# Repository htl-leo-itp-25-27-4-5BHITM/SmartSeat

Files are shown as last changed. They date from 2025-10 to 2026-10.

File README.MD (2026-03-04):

# SmartSeat

**Projektteam:**  
Daniel Riemer, Joschua Auer, Nino Tesar, Stefan Meinhart  
**Klasse:** 4BHITM – Schuljahr 2025/26  

---

## Projektübersicht

###
***TechStack***

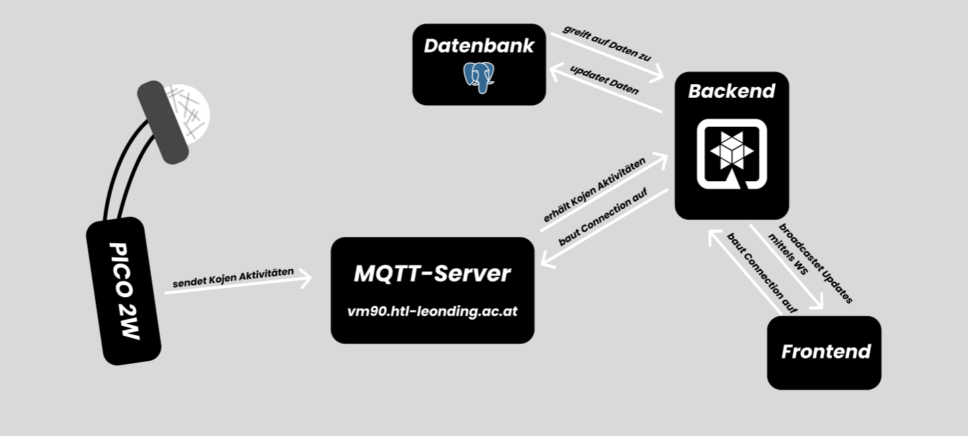
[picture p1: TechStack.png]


### Projektbezeichnung
**SmartSeat**

### Projektauftraggeber
- Dietmar Steiner  
- Christian Aberger  
- Dejan Sivak  

---

## Projekthintergrund und Motivation

Lernkojen sind fast durchgehend belegt, jedoch ist für Schüler auf den ersten Blick nicht ersichtlich, welche Koje aktuell frei ist.  
Die Suche nach einem freien Platz kann bis zu 10 Minuten dauern – Zeit, die verloren geht, da man bald wieder in den Unterricht zurückkehrt.

Auch für Lehrkräfte entstehen Probleme:
- Kommunikation mit Schülern ist oft umständlich.  
- Informationen oder organisatorische Hinweise müssen mehrfach einzeln übermittelt werden.  
- Das führt zu Unübersichtlichkeit, Missverständnissen und Frustration.

Das Projekt kann künftig auch für andere Orte wie Kindergärten, Kantinen oder allgemeine Platzverwaltungssysteme eingesetzt werden.

---

## Projektziele und Meilensteine

### 4. Klasse – 1. Semester
1. Web-App-Layout in Figma erstellt  
2. Grundstruktur der Web-App  
3. REST API aufgesetzt  
4. Datenbank aufgesetzt  
5. Raspberry-Pi-Kommunikation aufgebaut  

### 4. Klasse – 2. Semester
1. Karte in die App eingebunden  
2. App-Layout verfeinert  
3. Login implementiert  
4. Lehrerverwaltung eingebunden  

---

## Zielgruppe

- Schülerinnen und Schüler  
- Lehrkräfte  

---

## Technologie-Stack

### Software
- Backend: Quarkus  
- Datenbank: H2  
- Frontend: HTML, CSS, JavaScript (optional: Angular oder Vue)  
- Containerisierung: Docker  
- Microcontroller: MicroPython / C  

### Hardware
- Raspberry Pi Pico 2WH  
- Physischer Knopf  
- Ultraschallsensoren  

---

## SWOT-Analyse

| Kategorie | Punkte |
|---|---|
| **Strengths** | Gute Kenntnisse in SQL, HTML, CSS und JS |
| **Weaknesses** | Angular wird erst später gelernt; Quarkus ist noch neu; Datenübertragung zwischen Raspberry Pi, Quarkus und Datenbank kann komplex sein |
| **Opportunities** | Erweiterbar für viele andere Bereiche (z. B. Kindergärten, Kantinen, Raumbelegung) |
| **Threats** | Raspberrys könnten durch unsachgemäße Nutzung beschädigt werden |

---

## Sinn, Zweck und USP

### Ziel des Endprodukts
Eine Web-App, über die man sehen kann:
- Welche Lernkojen frei sind  
- Wo sich diese befinden  

In jedem Klassenraum hängt ein QR-Code, der direkt zur Website führt.

### Funktionen
- **Für Schüler:**  
  Nach dem Scannen sehen sie sofort freie Lernkojen.  
- **Für Lehrkräfte:**  
  Sie sehen, wo Schüler sitzen, und können Nachrichten an einzelne Kojen oder an die ganze Klasse senden.

### USP (Unique Selling Proposition)
Unsere Web-App macht freie Lernkojen auf einen Blick sichtbar, ermöglicht Schülern eine schnelle Kojensuche per QR-Code und bietet Lehrkräften gleichzeitig einen Überblick sowie eine direkte Kommunikationsmöglichkeit mit einzelnen Kojen oder der gesamten Klasse.

---

## Projektorganisation

| Name | Verantwortungsbereich |
|---|---|
| Nino Tesar | Backend |
| Daniel Riemer | Hauptsächlich Frontend |
| Joschua Auer | Hauptsächlich Frontend |
| Stefan Meinhart | Hardware |

---

© 2025 – SmartSeat Projektteam, 4BHITM

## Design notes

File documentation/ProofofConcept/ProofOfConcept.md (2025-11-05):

# Sensorbasierte Platzbelegung

---

## 1. Raspberry Pi Pico 2 WH

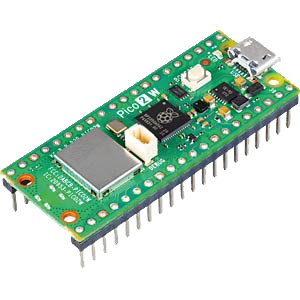
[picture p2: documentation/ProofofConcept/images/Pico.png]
Platzhalter für Raspberry Pi Pico Bild


[Produktlink bei Reichelt](https://www.reichelt.at/at/de/shop/produkt/raspberry_pi_pico_2_wh_rp235x_cortex-m33_wifi_microusb-398576)  
**Preis:** 9 €

### Beschreibung
Der **Raspberry Pi Pico 2 WH** wertet **Sensoren, Knöpfe und NFC-Daten** aus und sendet diese an das **Backend**.

---

### Vorteile
- Flexible **Sensor-Kombinationen** (Ultraschall, Knopf, Bewegung, NFC)  
- Viele **Hardware-Erweiterungen** verfügbar  
- Ideal für **schnelle Prototypen**  
- **Eigene Datenübertragung**, keine Fremd-APIs nötig  
- **Gut dokumentiert** & viele **Tutorials** verfügbar  

---

### Nachteile
- **Preis** summiert sich bei vielen Einheiten  
- **Zusammenbau** erforderlich → zusätzliche Kosten  
- **Programmierung** des Microcontrollers notwendig  

---

### Sensoren (Beispiele)

#### 🔸 Bewegungssensor (PIR HC-SR501)
- [Reichelt-Link](https://www.reichelt.at/at/de/shop/produkt/raspberry_pi_-_infrarot_bewegungsmelder_pir_hc-sr501-224216)  
- Reichweite: **3 m**  
- Preis: **2,30 €**

#### 🔸 Ultraschallsensor (HC-SR04)
- [Reichelt-Link](https://www.reichelt.at/at/de/shop/produkt/entwicklerboards_-_ultraschall_abstandssensor_hc-sr04-161487)  
- Messbereich: **3–400 cm**  
- Preis: **3,83 €**

#### 🔸 NFC-Modul (MFRC-522)
- [Reichelt-Link](https://www.reichelt.at/at/de/shop/produkt/entwicklerboards_-_rfid-modul_nxp_mfrc-522-192147)  
- Preis: **7 €**

#### 🔸 IR-Lichtschranken (2 × pro Koje)
- **Empfänger:** [IR-Empfänger](https://www.reichelt.at/at/de/shop/produkt/arduino_-_ir-empaenger-282519) → **1,56 €**  
- **Sender:** [IR-Sender](https://www.reichelt.at/at/de/shop/produkt/arduino_-_ir-sendermodul-282523) → **1,61 €**
> Solange die Lichtschranke unterbrochen ist, wird die Koje als **besetzt** markiert.

#### 🔸 Kabel
- Länge: **50cm * 20**
- Preis: **7,16€**

---

## 2. Tuya-Bewegungsmelder

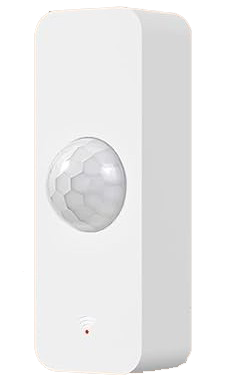
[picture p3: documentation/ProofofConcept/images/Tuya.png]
Platzhalter für Tuya-Bewegungsmelder Bild


[Amazon-Link](https://www.amazon.de/WiFi-Bewegungssensor-Bewegungsmelder-Heimsicherheit-Fernüberwachungs/dp/B0CLY2H1H6/)  
**Preis:** ca. **50 € (4 Stück)**  

---

### Zugriffsmöglichkeiten

#### 🔸 Lokale WLAN-Steuerung
- Schnellere Reaktion als Cloud-Steuerung  
- Notwendige Daten:  
  - **Device ID**, **Local Key**, **IP-Adresse**, **DP-Codes**  
- Tools: **tinytuya (Python)** kann Geräte im LAN scannen  
- Bewegungen → DP-Code (z. B. `101`) = `true/false`

#### 🔸 Cloud-Steuerung
- Über **Tuya IoT Console** ([iot.tuya.com](https://iot.tuya.com))  
- Geräteverknüpfung per **QR-Code**  
- Zugriff auf **Device ID**, **Local Key**, **DP-Codes**  
- Integration in eigene Software möglich
- **KO Kriterien:**
  - 1 Monat Free Trial
  - Standard Version: 300€ pro Monat  

---

### Integration mit Quarkus REST API
- Statusabfrage über **Listener (Push)** oder **Polling**  
- **Port:** 6668  
- **Verschlüsselung:** AES-128-ECB  

---

### Technische Daten

| Merkmal | Wert |
|---|---|
| Typ | Drahtloser Bewegungsmelder |
| Reichweite | 6 m |
| Stromversorgung | Batterie |
| Anzahl / Preis | 4 Stk. ≈ 50 € |
| Technologie | Infrarot, WiFi |
| Laufzeit | Bis zu 6 Monate |
| Stromverbrauch | Niedrig |

---

## 3. Ultraschallsensoren (Alternative Lösung)

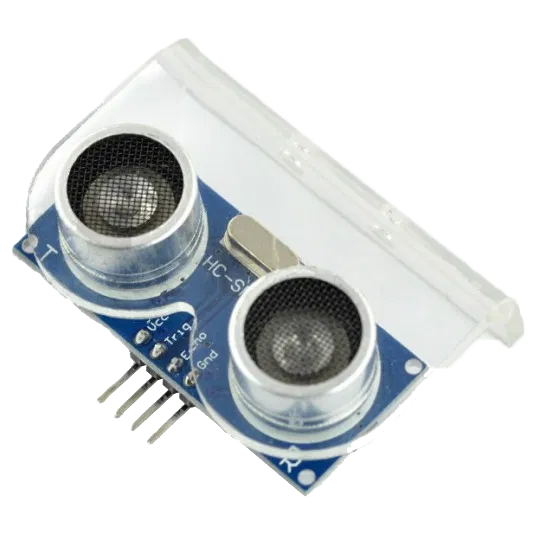
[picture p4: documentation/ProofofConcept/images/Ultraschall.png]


[Botland-Link](https://botland.de/ultraschall-abstandssensoren/5686-ultraschall-abstandssensor-hc-sr04-2-200cm-montagehalterung-5904422308452.html)  
**Preis:** 3 € pro Stück → mind. 2 Sensoren nötig  

---

### Vorteile
- Sehr **günstig**  
- **Einfache Verwendung**  
- Bereits **bekannte Technologie**

### Nachteile
- **Fehlauslösung** möglich (Objekt im Weg)  
- **Unzuverlässig** bei bestimmten Materialien oder Winkeln  
- **Weitere Hardwarekomponenten** nötig  

---

## 4. NFC-Reader (für Platzbelegung)

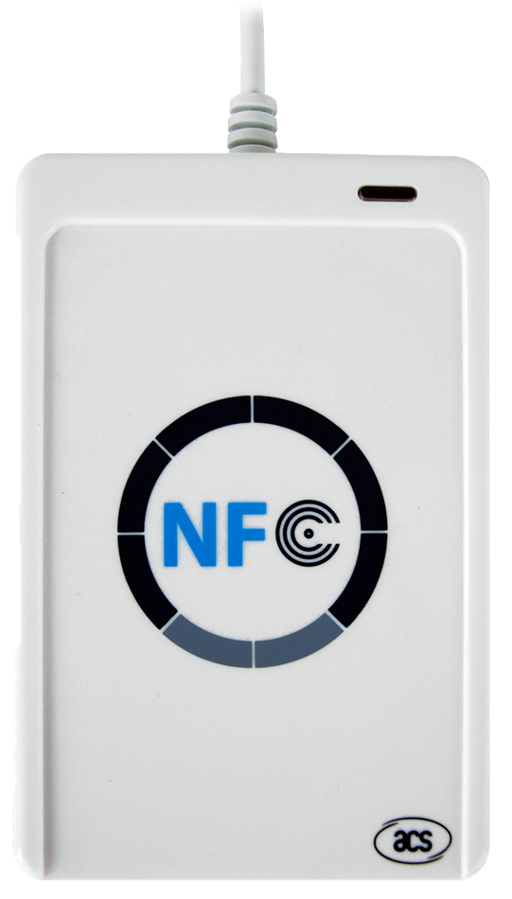
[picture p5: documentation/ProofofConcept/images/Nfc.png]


### Funktionsprinzip
Beim Platznehmen hält der Schüler sein **Smartphone oder Karte** an den **NFC-Reader**.  
→ Die Koje wird in der Datenbank als **„besetzt“** markiert.  
Beim Verlassen wiederholt er den Vorgang → **„frei“**.

---

### Vorteile
- Sehr **praktisch** – Handy ist immer dabei  
- **Schnelle Anmeldung**

### Nachteile
- **Nicht jedes Handy** unterstützt NFC-HCE  
- **Apple-Geräte** nur eingeschränkt kompatibel  
- **Nur Teil der Nutzer** kann das Feature verwenden  
- Benötigt speziellen **NFC-Reader mit HCE-Unterstützung**

---

## Zusammenfassung (Vergleich)

| Komponente | Preis | Vorteile | Nachteile |
|---|---|---|---|
| **Raspberry Pi Pico 2 WH** | 9 € | Erweiterbar, dokumentiert | Aufbau & Programmierung nötig |
| **Tuya-Bewegungsmelder** | 50 € (4 Stk.) | WLAN & Cloud ready | Teilweise Cloud-abhängig |
| **Ultraschallsensoren** | 3 €/Stk. | Günstig & einfach | Fehleranfällig |
| **NFC-Reader (ESP32 + NFC)** | 55 € | Handy-Integration | Nicht alle Geräte kompatibel |

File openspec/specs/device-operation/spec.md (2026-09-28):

# Device Operation Specification

## Purpose

Defines how the supported Raspberry Pi Pico 2 W motion-sensor unit starts, observes a seat, publishes data, reconnects, and exposes diagnostics.

## Requirements

### Requirement: Supported baseline device
The baseline occupancy device SHALL be a Raspberry Pi Pico 2 W connected to one motion sensor whose signal output is wired to GPIO 18, with appropriate power and ground connections.

#### Scenario: Correctly wired startup
- **WHEN** the device receives stable USB power and the sensor is wired to the documented pins
- **THEN** the firmware initializes the GPIO input without requiring an interactive start command

### Requirement: Network startup
The device SHALL use externally supplied Wi-Fi and MQTT configuration, connect to the configured network, and establish an MQTT session before publishing observations.

#### Scenario: Network available
- **WHEN** configured Wi-Fi and MQTT services are reachable
- **THEN** the device connects and becomes ready to publish observations

#### Scenario: Network unavailable at boot
- **WHEN** Wi-Fi or MQTT is unavailable during startup
- **THEN** the device reports the failure through diagnostics and continues bounded reconnection attempts without crashing

### Requirement: Seat-specific observation publication
Each device SHALL be configured with one seat identifier and SHALL publish observations using the sensor-ingestion contract when motion state changes.

#### Scenario: Motion begins
- **WHEN** the motion sensor changes from no motion to motion detected
- **THEN** the device publishes the configured seat identifier with `status=false`

#### Scenario: Motion ends
- **WHEN** the motion sensor changes from motion detected to no motion
- **THEN** the device publishes the configured seat identifier with `status=true`

### Requirement: Continued occupancy refresh
While motion remains detected, the device SHALL publish observations often enough to prevent a genuinely occupied seat from expiring solely because no edge transition occurred.

#### Scenario: Continuous motion state
- **WHEN** a seat remains occupied longer than the configured inactivity duration
- **THEN** periodic valid observations refresh the backend last-observed time without creating another interval

### Requirement: Connection recovery
The device SHALL recover from temporary Wi-Fi or MQTT loss and resume publication without requiring a power cycle under normal recoverable conditions.

#### Scenario: MQTT connection drops
- **WHEN** an established MQTT connection is lost
- **THEN** the device retries with bounded backoff and publishes the current observation after reconnecting

### Requirement: Local diagnostics
The device SHALL make startup, connection, publication, and unrecoverable error status observable through its serial diagnostic output without printing reusable secrets.

#### Scenario: Inspect serial output
- **WHEN** an operator connects a serial monitor to the device
- **THEN** the output identifies operational state and failures without revealing Wi-Fi or MQTT passwords

### Requirement: Prototype alternatives remain excluded
NFC, Tuya, ultrasonic, button, and infrared-barrier devices SHALL NOT be required for baseline operation unless adopted by a later approved specification change.

#### Scenario: Baseline acceptance test
- **WHEN** SmartSeat is tested against this baseline
- **THEN** the test does not require any excluded proof-of-concept sensor technology

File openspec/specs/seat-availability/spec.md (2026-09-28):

# Seat Availability Specification

## Purpose

Defines how people discover current learning-seat availability without authentication and how the view remains accurate as occupancy changes.

## Requirements

### Requirement: Public availability access
The system SHALL allow a user to view seat availability without signing in.

#### Scenario: Open availability view
- **WHEN** a user opens the SmartSeat public entry point
- **THEN** the system displays the current seat-availability view without requesting credentials

#### Scenario: Administrative functions remain separate
- **WHEN** an unauthenticated user uses the public availability view
- **THEN** the system does not expose controls that modify seats, configuration, accounts, or history

### Requirement: Seat availability presentation
The system SHALL present each configured seat with its stable identifier, display name, floor, wing, and canonical state of `FREE`, `OCCUPIED`, or `UNKNOWN`.

#### Scenario: Display free and occupied seats
- **WHEN** the current catalog contains seats in free and occupied states
- **THEN** the map and list distinguish those states consistently and provide a textual state indicator in addition to color

#### Scenario: Display unknown state
- **WHEN** the system cannot establish a trustworthy current state for a configured seat
- **THEN** the public view identifies the seat as `UNKNOWN` rather than reporting it as free

### Requirement: Location filtering and counts
The system SHALL allow users to filter seats by configured location and SHALL calculate free-seat counts from the same filtered dataset shown to the user.

#### Scenario: Filter by floor
- **WHEN** a user selects a floor
- **THEN** only seats assigned to that floor are shown and the free-seat count reflects those seats

#### Scenario: Location has no seats
- **WHEN** a user selects a known location that has no configured seats
- **THEN** the system shows an empty result and a free-seat count of zero without reporting an error

### Requirement: Live availability updates
The system SHALL deliver a complete current seat snapshot when a realtime connection is established and SHALL publish subsequent state or catalog changes to connected clients.

#### Scenario: Realtime state change
- **WHEN** an occupied seat becomes free or a free seat becomes occupied
- **THEN** connected public views update that seat without requiring a page reload

#### Scenario: Reconnect after interruption
- **WHEN** a client restores a lost realtime connection
- **THEN** the system sends a fresh complete snapshot before applying later incremental changes

### Requirement: Current occupancy duration
The system SHALL show the elapsed duration of the current occupancy interval for an occupied seat and SHALL omit that duration for free or unknown seats.

#### Scenario: Occupied seat duration
- **WHEN** a user inspects a seat with an active occupancy interval
- **THEN** the displayed elapsed duration is derived from the recorded interval start and the current time

#### Scenario: Seat becomes free
- **WHEN** an occupied seat transitions to free
- **THEN** the public view stops displaying an active occupancy duration for that seat

### Requirement: Location-specific QR entry
The system SHALL support QR-code URLs that open the public availability view with a configured location already selected.

#### Scenario: Valid location QR code
- **WHEN** a user follows a QR-code URL for a known location
- **THEN** the public view opens with that location filter applied

#### Scenario: Invalid location QR code
- **WHEN** a QR-code URL references an unknown location
- **THEN** the system shows the unfiltered availability view and explains that the requested location was not found

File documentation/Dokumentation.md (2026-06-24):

# **Smartseat Gebrauchsanweisungs**

## MQTT und der Sensor

Damit wir wissen welche Kojen besetzt sind, verweden wir einen Pico 2W mit einem Bewegungssensor.

### Entwicklung 

Für Entwicklungszwecken kann man die MQTT-Eingaben, durch Programme wie MQTT-Explorer simulieren, dabei verwenden wir den MQTT Server vom Herrn Professor Stützt.

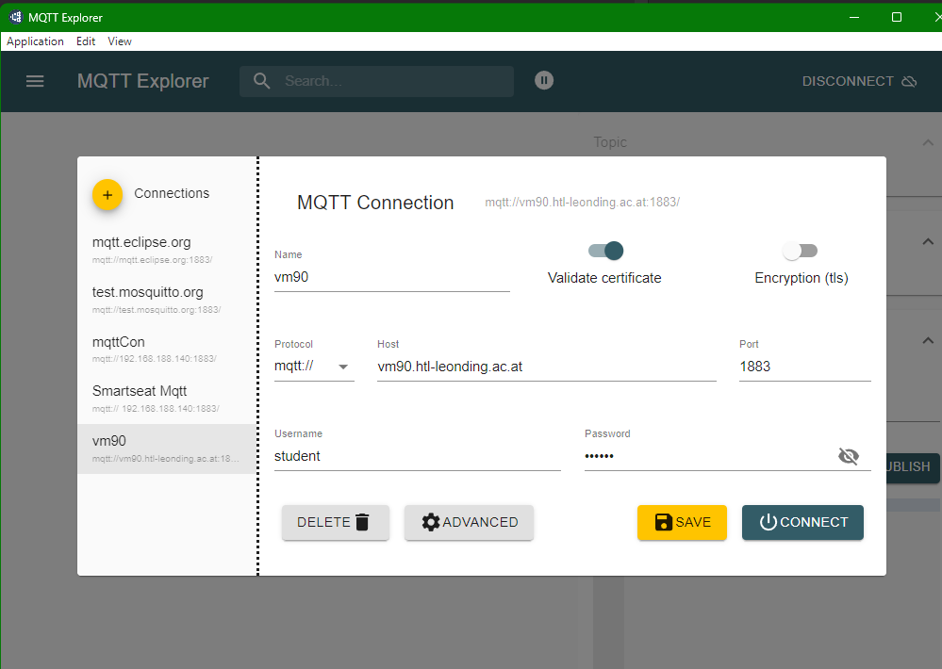
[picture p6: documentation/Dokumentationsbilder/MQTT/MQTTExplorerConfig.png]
Mqttexplorer Anbindung


Als nächstes muss das neue Topic `pico-data` erstellt werden. Danach muss man unten JSON auswählen. Dieses JSON besitzt einen `id` und `status` Parameter, wobei der `id` Parameter für genau eine Koje da ist und der `status` Parameter die Statusänderung angebit, dabei kann man die genaue Struktur unten auslesen. 

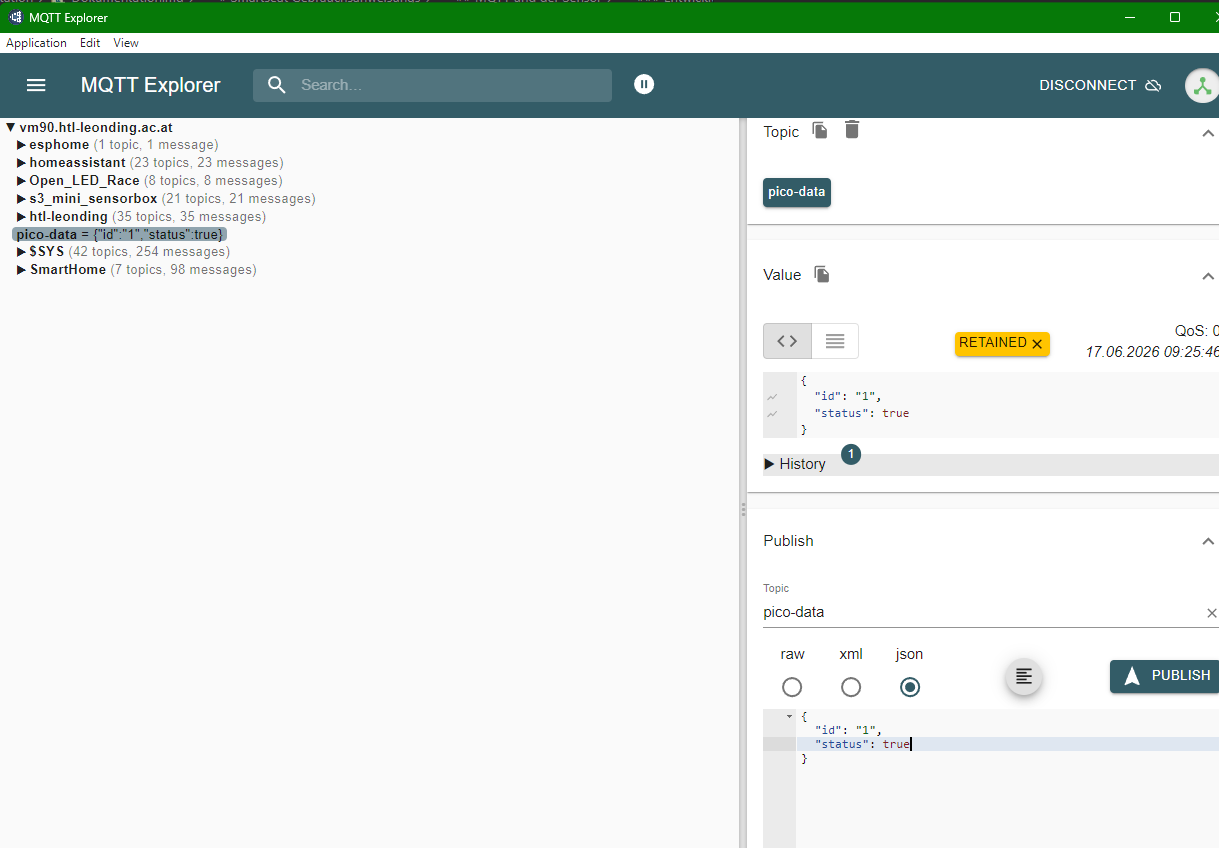
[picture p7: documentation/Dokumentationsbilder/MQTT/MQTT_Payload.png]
Mqtt Payload


### Normale Verwendung 

#### Pico 2W

Im Echtbetrieb brauchen die Sensoren eine USB-Schnittstelle die 5V liefert, da das Programm direkt startet sobald der Pico mit Strom beliefert wird, und einen Router, wodurch sich der Pico mit dem Internet verbinden kann. Wir verweden unser eigenkonfiguriertes WLAN namens Smartseat, wofür wir unseren Router verweden. Man sollte den Pico erst einschalten sobalt der Router `blau` und nicht mehr `rot` leuchtet. 

Damit man aber nachschauen kann was der Pico wirklich macht, kann man ihn an einem PC, über USB, anschließen. Doch das man die Ausgabe sehen kann braucht man ein paar Sachen: 

1. Visual Studio Code, bzw ein Terminal 
2. Serial Monitor Erweiterung 

Sobald der Pico angeschlossen ist muss man bei dem Serial Monitor COM5, bzw serielles USB-Gerät auswählen und auf das Play Symbol klicken. Nun kann man sehen was der Pico macht. Solang er nicht irgeneinen Fehler wirft, befindet er sich im Normalbetrieb. 

#### Sensor 

Das der Sensor nicht kaputt geht, muss man diesen, mit dem Pico, richtig verkabeln. Es gibt dadbei 3 Kabel; VCC (Spannung), Ground und die Ausgabe.

1. VCC (Sensor) auf VSYS (Pico) 
2. GND (Sensor) auf GND (Pico)
3. SIG (Sensor) auf GP18 

Hier unten sieht man welcher Pin, welcher ist.

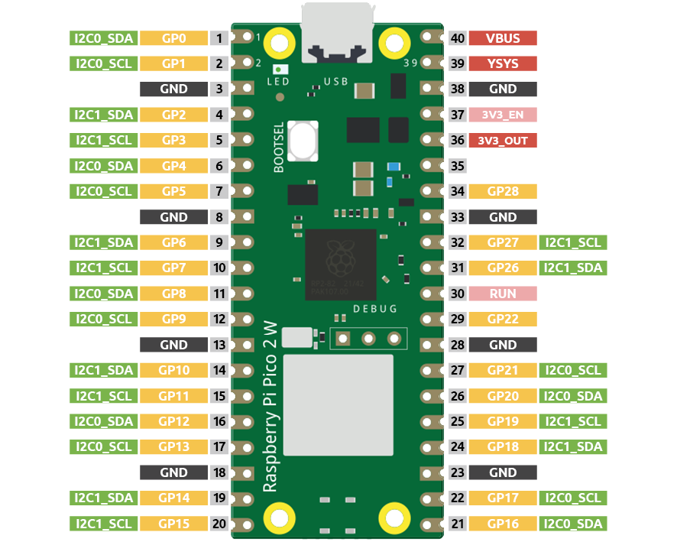
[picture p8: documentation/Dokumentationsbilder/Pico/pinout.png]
Pico PINS


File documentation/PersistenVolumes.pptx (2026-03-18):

## Persistent Volumes

Joschua Auer, Stefan Meinhart, Daniel Riemer, Nino Tesar

## Problem: Container sind ephemer

- Pods sind kurzlebig
  - Neustart oder Löschung = Datenverlust
  - Lokaler Speicher ist nicht persistent

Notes: Pods werden gelöscht und neu gestartet wenn: auf einem Node kein Platz mehr ist oder sie ausfallen

## Was passiert ohne Persistent Volume?

- Daten liegen nur im Container-Dateisystem
  - Pod wird gelöscht → Daten sind weg
  - Pod wird neu erstellt → leeres Dateisystem
  - Nicht geeignet für produktive, zustandsbehaftete Anwendungen

## Warum brauchen wir persistenten Speicher?

- Datenbank
  - Benutzerinteraktionen
  - Logs

## Die drei Kernobjekte

- PersistentVolume (PV)
- PersistentVolumeClaim (PVC)
- Pod mit Volume-Mount

## PersistentVolume (PV)

- Speicherressource im Cluster
- Wird vom Administrator erstellt
- Definiert Kapazität und Access Mode

## PersistentVolumeClaim (PVC)

- Speicheranforderung eines Pods
- Definiert Größe und Access Mode
- Kubernetes matched automatisch mit PV

## Zusammenspiel

- Pod → PVC → PV → Physischer Speicher
  - PVC wird erstellt
  - Kubernetes bindet passendes PV
  - Pod mountet PVC
  - Daten bleiben auch nach Neustart erhalten

## StorageClass

- Automatische Erstellung von PersistentVolumes
  - Kein manuelles Anlegen von PV notwendig
  - Besonders wichtig in Cloud-Umgebungen

## Best Practices

- Kein hostPath in Produktion verwenden
  - StorageClass nutzen
  - Backups einplanen
  - Access Modes richtig wählen

## Fazit

- Pods sind austauschbar und flüchtig
  - Internes Dateisystem geht bei Neustart verloren
  - Ohne PV verschwinden Daten
  - Persistenter Speicher ist Voraussetzung für produktive Workloads

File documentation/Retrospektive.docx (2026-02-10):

SmartSeat – Retrospektive

(Start, Stop, Continue)

Team:

Joshua Auer, Stefan Meinhart, Daniel Riemer und Nino Tesar.

Start:

Es ist wichtig, dass wir als Team anfangen unsere Stunden, die wir gearbeitet haben, sauber und sofort in Clockify einzutragen mit besseren Bezeichnungen.

Noch dazu wäre es von Vorteil, wenn wir uns an neuen Problemfindungsweisen und Arten der Recherche zur Fehlerbehebung gewöhnen.

Stop:

Wir sollten darauf achten, dass wir pünktlich und konsistent erscheinen, um bei Arbeitszeiten und Reviews anwesend zu sein.

Wir müssen bei den nächsten Sprints darauf achten, dass wir uns als Team nicht überladen und Sprints, welche zu anspruchsvoll sind, nicht anzunehmen.

Continue:

Bei uns ist bereits eine starke Begeisterung für das Projekt vorhanden und diese wollen wir um jeden Preis beibehalten.

Unser Github-Repository ist gut strukturiert und vollständig. Dies soll auch weiterhin so bleiben.

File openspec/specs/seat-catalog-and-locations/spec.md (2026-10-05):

# Seat Catalog and Locations Specification

## Purpose

Defines the stable seat and location catalog used by public availability, sensor mapping, administration, and historical reporting.

## Requirements

### Requirement: Stable seat identity
Each seat SHALL have a stable system identifier that remains unchanged when its display name or location metadata changes.

#### Scenario: Rename a seat
- **WHEN** an administrator changes a seat display name
- **THEN** the seat retains its identifier and existing history remains associated with it

### Requirement: Seat location metadata
Each seat SHALL reference a valid location containing at least a floor and wing value.

#### Scenario: Return seat location
- **WHEN** a client requests the seat catalog
- **THEN** each seat includes the floor and wing of its assigned location

#### Scenario: Invalid location assignment
- **WHEN** an administrative operation attempts to assign a seat to an unknown location
- **THEN** the system rejects the operation without changing the seat

### Requirement: Unique validated display names
The system SHALL require each seat display name to be non-blank and unique after trimming whitespace, while treating submission of the seat's own unchanged normalized name as a successful no-op.

#### Scenario: Successful rename
- **WHEN** an authorized administrator submits a non-blank name that no other seat uses
- **THEN** the system updates the name and publishes the updated catalog

#### Scenario: Save unchanged name
- **WHEN** an authorized administrator submits the target seat's existing name with no normalized change
- **THEN** the system reports success, preserves the catalog, and does not publish a false error

#### Scenario: Duplicate rename
- **WHEN** an authorized administrator submits a name already used by another seat
- **THEN** the system rejects the rename with a conflict response and preserves both existing names

### Requirement: Seat map placement metadata
Each configured seat SHALL have map placement metadata sufficient to position its marker on the map for its assigned floor without relying on contiguous identifiers or fixed seat counts.

#### Scenario: Render catalog seat on its floor
- **WHEN** a configured seat includes valid floor and placement metadata
- **THEN** the public map displays its marker at the configured position on the matching floor map

#### Scenario: Missing or invalid placement
- **WHEN** a configured seat lacks valid map placement metadata
- **THEN** the seat remains available in a textual representation and the system does not place it at another seat's position

### Requirement: Catalog-sized behavior
All availability, lifecycle, and analytics behavior SHALL derive the number and identifiers of seats from the configured catalog rather than assuming a fixed count or contiguous identifiers.

#### Scenario: More than five seats
- **WHEN** the catalog contains more than five seats
- **THEN** every configured seat can be displayed, updated, and included in analytics

#### Scenario: Non-contiguous identifiers
- **WHEN** configured seat identifiers contain a gap
- **THEN** the system processes the existing identifiers without creating placeholder seats or indexing failures

### Requirement: Unknown seat handling
Operations that reference a seat SHALL reject unknown identifiers without modifying another seat or creating implicit catalog entries.

#### Scenario: Unknown seat update
- **WHEN** a client or device submits an operation for an unknown seat identifier
- **THEN** the system leaves the catalog and all seat states unchanged and reports the rejected reference through the appropriate error channel

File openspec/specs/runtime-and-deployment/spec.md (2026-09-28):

# Runtime and Deployment Specification

## Purpose

Defines the operational environment that keeps SmartSeat data durable, configuration externalized, dependencies observable, and service recovery predictable.

## Requirements

### Requirement: Durable production data
Production seat catalog, configuration, active occupancy information, accounts, and history SHALL survive application and database container restarts.

#### Scenario: Application restart
- **WHEN** the application restarts normally
- **THEN** previously committed production data remains available and consistent

#### Scenario: Production startup
- **WHEN** the production service starts
- **THEN** it uses non-destructive schema migration or validation rather than dropping and recreating the schema

### Requirement: Externalized configuration and secrets
Database, MQTT, network, logging, and authentication settings SHALL be supplied through deployment configuration, and reusable secrets SHALL not be committed as production defaults.

#### Scenario: Missing required secret
- **WHEN** a required production credential is absent
- **THEN** the affected component fails readiness with a diagnostic that does not reveal another secret

### Requirement: Dependency health
The runtime SHALL expose health information that distinguishes application liveness from readiness of required dependencies such as the database and MQTT connection.

#### Scenario: Database unavailable
- **WHEN** the application process is running but cannot use its database
- **THEN** liveness may remain healthy while readiness reports the database failure

#### Scenario: MQTT unavailable
- **WHEN** the broker is unavailable
- **THEN** health information reports degraded ingestion while read-only behavior backed by available persisted data remains observable

### Requirement: Operational logging
The runtime SHALL log application startup, dependency changes, rejected sensor messages, lifecycle failures, realtime connection failures, and administrative audit events with timestamps and useful identifiers.

#### Scenario: Sensor message rejected
- **WHEN** ingestion rejects a message
- **THEN** the logs identify the rejection category and affected identifier when safely available without recording credentials

### Requirement: Realtime recovery
The runtime SHALL allow clients to reconnect to the seat-update channel after application or network interruption and obtain a fresh authoritative snapshot.

#### Scenario: Application is redeployed
- **WHEN** the service becomes available after redeployment
- **THEN** reconnecting clients receive the current catalog and states before later updates

### Requirement: Environment-specific development data
Schema recreation, seeded credentials, and synthetic history SHALL be limited to explicitly selected development or test profiles.

#### Scenario: Development profile
- **WHEN** an operator explicitly starts a development profile
- **THEN** documented seed or schema-reset behavior may run without changing production policy

#### Scenario: Production profile
- **WHEN** the production profile starts
- **THEN** the runtime neither recreates the schema nor installs documented development credentials

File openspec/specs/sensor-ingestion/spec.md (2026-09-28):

# Sensor Ingestion Specification

## Purpose

Defines the MQTT observation contract and the validation and reliability rules that convert sensor messages into trustworthy seat-lifecycle input.

## Requirements

### Requirement: MQTT observation contract
The ingestion service SHALL consume JSON observations from the configured `pico-data` channel containing a seat `id` and boolean `status`. For compatibility, a numeric identifier or a string containing only a positive integer SHALL be accepted. `status=false` SHALL mean occupancy detected; `status=true` SHALL mean no active motion and SHALL not by itself release the seat.

#### Scenario: Occupancy observation
- **WHEN** the service receives `{"id":"1","status":false}` for a configured seat
- **THEN** it submits a valid occupancy observation to that seat's lifecycle

#### Scenario: No-motion observation
- **WHEN** the service receives a valid observation with `status=true`
- **THEN** it does not immediately release an occupied seat and allows inactivity timeout rules to determine release

### Requirement: Payload validation
The ingestion service SHALL reject malformed JSON, missing fields, non-boolean status values, non-positive identifiers, and identifiers that do not map to a configured seat.

#### Scenario: Malformed message
- **WHEN** a message cannot be parsed according to the observation contract
- **THEN** no seat state changes and the rejection is logged without exposing credentials or secrets

#### Scenario: Unknown device mapping
- **WHEN** a syntactically valid observation references an unknown seat identifier
- **THEN** no catalog entry or seat state is created implicitly and the unknown mapping is recorded

### Requirement: Duplicate delivery tolerance
The ingestion service SHALL tolerate duplicate delivery without creating duplicate occupancy intervals or history records.

#### Scenario: Duplicate occupied message
- **WHEN** the same occupied observation is delivered more than once while the seat is occupied
- **THEN** the active interval remains singular and only the last-observed time may be refreshed

### Requirement: Retained and stale message safety
Retained or otherwise stale observations SHALL NOT keep a seat occupied indefinitely or start a new interval when their freshness cannot be established.

#### Scenario: Stale retained occupancy
- **WHEN** the service subscribes and receives an occupied retained message that cannot be established as current
- **THEN** it does not start or extend an occupancy interval solely from that message

### Requirement: Ingestion continuity
Temporary MQTT disconnection SHALL not corrupt existing seat state, and the service SHALL resume validation and processing after reconnection.

#### Scenario: Broker unavailable
- **WHEN** the MQTT broker becomes unavailable
- **THEN** the service records the connectivity failure and leaves existing seat states to their lifecycle timeout rules

#### Scenario: Broker reconnects
- **WHEN** the MQTT connection is restored
- **THEN** the service resumes consuming observations without creating duplicate intervals from redelivery

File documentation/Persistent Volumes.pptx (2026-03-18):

## Persistent Volumes

Daniel, Nino, Stefan, Joshua

## Wieso? 01

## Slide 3

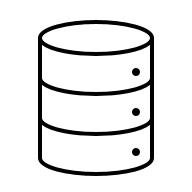
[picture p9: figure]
Datenbank Silhouette
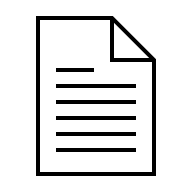
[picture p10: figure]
Dokument Silhouette

Daten gehen veloren

Datei teilen

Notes: Daten gehen verloren, wenn der Container abstürzt
Mehre Containers in einem Pod können nicht miteinander reden, da sie alle ihr eigenes Dateisystem verwenden

## Funktion 02

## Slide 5

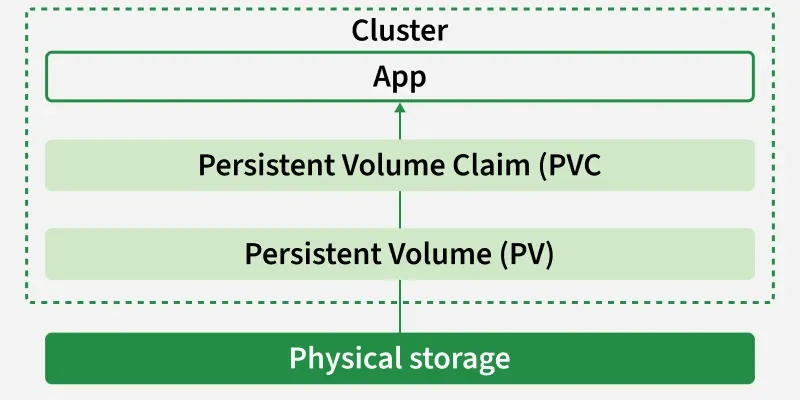
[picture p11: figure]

## PV-Persistent Volumes

- Cluster level Storage Resource
- Dauerhafte Speicherung unabhängig von den Pods
- Volume plugin
- Gehört keinen Pod an

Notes: Kann nicht mit einem Pod sprechen

## PVC-PersistentVolume Claim

- Anfrage
- Brücke zwischen Pods und PV
- Kann eigene PVs erzeugen (StorageClass)

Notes: Kann nicht mit einem Pod sprechen

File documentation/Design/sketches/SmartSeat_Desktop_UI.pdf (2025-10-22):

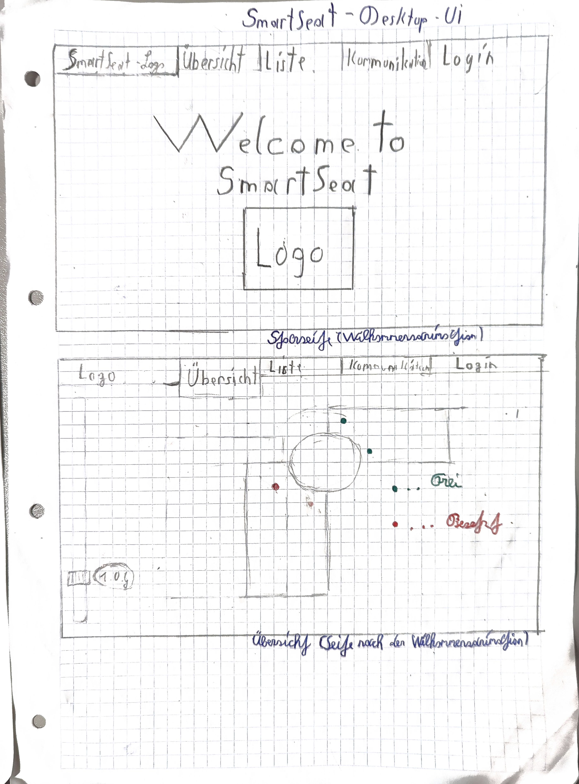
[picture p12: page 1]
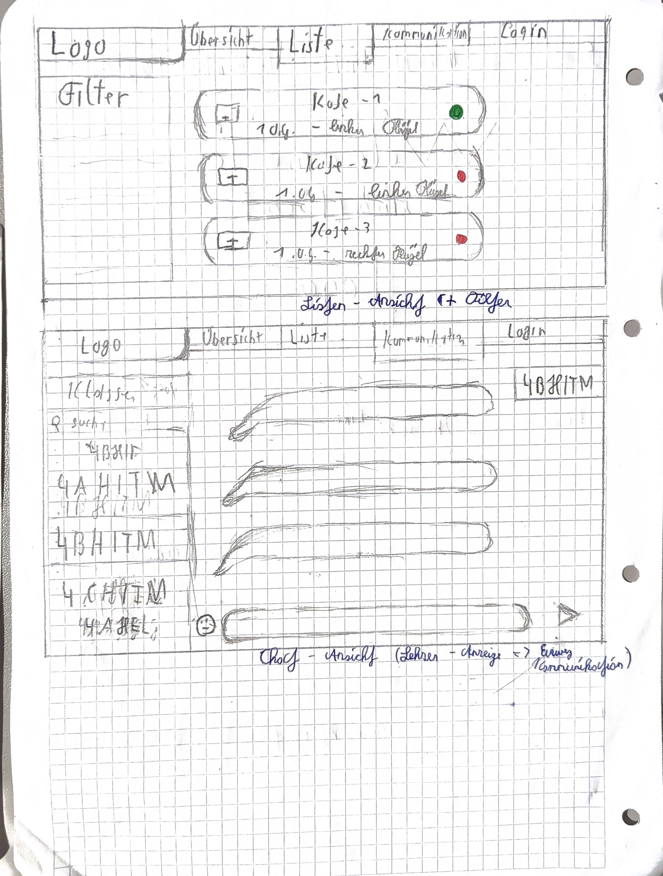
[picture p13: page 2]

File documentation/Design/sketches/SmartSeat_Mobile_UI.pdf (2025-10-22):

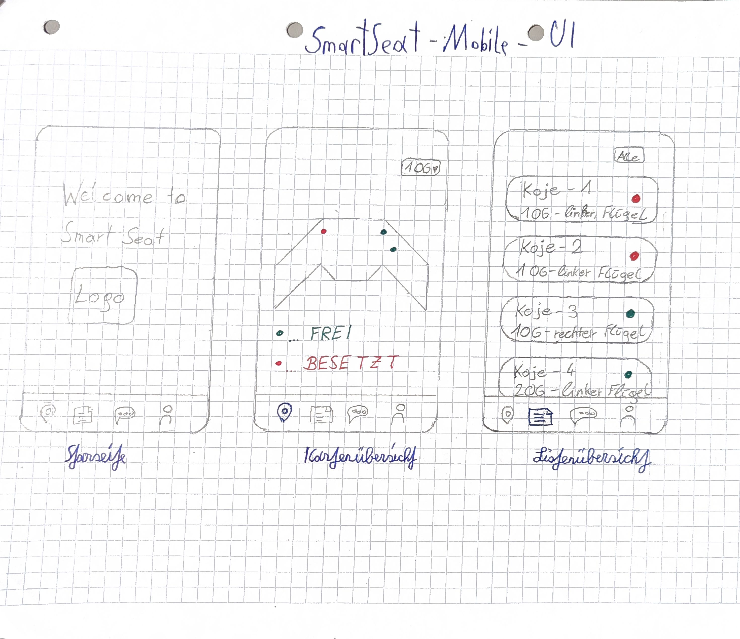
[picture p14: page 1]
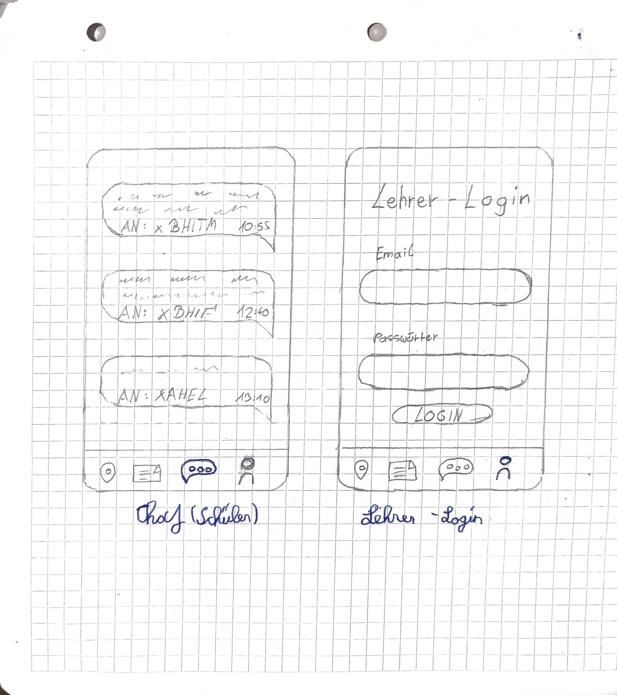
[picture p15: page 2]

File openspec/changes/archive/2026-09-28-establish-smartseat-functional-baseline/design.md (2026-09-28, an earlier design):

# Design

## Context

See `proposal.md` for motivation and scope. SmartSeat currently combines a Quarkus application, static browser clients, PostgreSQL, MQTT ingestion, a WebSocket update channel, and Raspberry Pi Pico firmware. Functional intent is distributed across source code, generated framework documentation, project documents, hand-drawn UI sketches, Figma frames, proof-of-concept research, and hardware models.

The current implementation demonstrates the main end-to-end path but does not yet provide a stable contract. Notable constraints include inverted boolean state naming, timeout-driven release, client-only dashboard gating, fixed five-seat analytics, destructive schema initialization, and alternative hardware concepts that were investigated but not selected. The project has no pre-existing durable OpenSpec capabilities, so this change creates the initial baseline.

## Goals / Non-Goals

**Goals:**

- Establish one canonical vocabulary and state model across browser, API, persistence, MQTT, analytics, and firmware behavior.
- Make each externally observable behavior traceable to current source, project intent, or an explicit baseline decision.
- Keep capability boundaries small enough for later implementation threads while preserving cross-capability invariants.
- Allow the planning work to be reviewed and refined across sequential threads without modifying runtime source.
- Separate production requirements from development conveniences and proof-of-concept alternatives.

**Non-Goals:**

- Implementing or refactoring application, database, frontend, container, or firmware code in this change.
- Preserving implementation defects as required behavior merely because they exist today.
- Requiring Kubernetes because the documentation folder contains presentations about persistent volumes.
- Selecting NFC, Tuya, ultrasonic, button, or infrared-barrier hardware for the baseline.
- Supporting direct communication, chat, messaging, announcements, or notifications between teachers and students. Those concepts are deprecated even where historical proposal text or UI designs show them.

## Decisions

### Decision: Use one baseline change with eight capability specifications

The specification is partitioned by externally observable responsibility: availability, catalog, lifecycle, ingestion, administration, analytics, device operation, and runtime deployment. The shared proposal and design hold scope and cross-cutting decisions.

This is preferred over one change per capability because the initial baseline depends on shared definitions for seat identity, state, time, authentication, and persistence. Separate changes would allow those definitions to drift before any durable specification exists.

### Decision: Apply a fixed evidence precedence

Conflicts are resolved in this order:

1. Explicit user decisions, especially the communication exclusion.
2. Approved decisions in this proposal and design.
3. Source code, tests, configuration, and seed data as evidence of current behavior.
4. Project proposal, operating documentation, use cases, and current UI designs as evidence of product intent.
5. Proof-of-concept alternatives and older sketches.
6. Generic or unrelated supporting material.

An observed implementation behavior can justify a compatibility scenario but cannot silently override an explicit product decision. An aspirational document can motivate a requirement only when it fits the approved baseline.

### Decision: Use a canonical three-state model

The functional contract uses `FREE`, `OCCUPIED`, and `UNKNOWN` rather than exposing boolean storage fields.

```text
                    accepted occupancy observation
        +----------------------------------------------+
        |                                              v
     +------+                                      +----------+
     | FREE |                                      | OCCUPIED |
     +------+                                      +----------+
        ^                                              |
        | timeout or authorized correction             |
        +----------------------------------------------+

     inconsistent or unrecoverable state --> UNKNOWN
     valid transition from known evidence  --> FREE or OCCUPIED
```

`UNKNOWN` prevents missing or inconsistent data from being reported as a free seat. Persistence adapters may retain the existing boolean column temporarily, but API and domain boundaries must map it explicitly.

The alternative was to define the current `status=true` value as the public contract. That was rejected because the name is ambiguous, the database column means `unoccupied`, and the firmware sends the inverse of detected motion.

### Decision: Define motion as occupancy evidence and release by timeout

For compatibility with the active firmware, MQTT `status=false` means motion or occupancy detected. `status=true` means no active motion, but it does not immediately mark a seat free. Accepted occupied observations refresh `lastObservedAt`; the original `occupiedSince` remains unchanged. The configured inactivity duration ends the interval.

Immediate release on a no-motion edge was rejected because a PIR sensor can stop reporting motion while a person remains seated. Timeout release is retained, but its state and history update must be atomic.

Retained or stale messages must not create phantom occupancy. The ingestion adapter must use broker metadata or a freshness policy when establishing whether a retained observation is current.

### Decision: Use the configured catalog as the source of seat cardinality

All views, updates, and analytics iterate configured seat identifiers. Fixed arrays of five elements and `id - 1` indexing are implementation gaps. Stable identifiers preserve history through renames and do not require identifiers to be contiguous.

The baseline does not require a full create/delete-seat administration interface. It requires the runtime behavior to work for any valid configured catalog and covers the currently demonstrated rename operation.

### Decision: Require server-side administrative sessions

Successful login must create a server-recognized session, and every modifying endpoint must enforce it. Browser `sessionStorage` can remain a presentation convenience but cannot be the authorization boundary. Passwords use an adaptive one-way hash, sessions expire, logout invalidates the server session, and sensitive values never appear in responses or ordinary logs.

Keeping the current client-only gate was rejected because a caller can bypass it and invoke dashboard endpoints directly.

### Decision: Model history as completed occupancy intervals

Each completed interval records seat identity, start, end, and duration. Existing storage may derive start from `endedAt - duration`, but the contract treats both boundaries as part of the interval semantics.

Per-seat averages measure occupancy duration, not waiting time. Hourly utilization sums interval overlap in each clock hour and caps the result at one hour per seat-hour. Taking only the maximum overlap was rejected because it undercounts multiple valid intervals within the same hour.

All date calculations use one externally documented application time zone. The default deployment should use `Europe/Vienna` unless deployment configuration explicitly selects another supported zone.

### Decision: Adopt Pico 2 W plus PIR as the baseline device

The active device path is a Raspberry Pi Pico 2 W with a motion sensor on GPIO 18, powered by USB and publishing to MQTT. Continuous occupancy needs periodic refresh messages in addition to edge messages so the inactivity timeout does not release a genuinely occupied seat.

NFC, Tuya, ultrasonic, button, and infrared-barrier concepts remain research inputs rather than required runtime dependencies. Adopting one later requires a separate specification change that defines its observation semantics.

### Decision: Separate production durability from development reset behavior

Production uses durable PostgreSQL storage and non-destructive schema evolution. Schema recreation, seeded accounts, and synthetic history are permitted only in explicit development or test profiles. Configuration and secrets come from the deployment environment.

The current unconditional `drop-and-create` behavior is treated as a development default that must not define production behavior.

### Decision: Use full snapshots as the realtime recovery boundary

The WebSocket channel sends a complete authoritative snapshot at connection and reconnection. Subsequent changes may be broadcast as complete snapshots or incremental messages, provided clients can order them and converge on the same state.

This avoids relying on a client to reconstruct changes missed during a network or application interruption.

### Decision: Maintain traceability in the change artifacts

Requirements use stable capability paths and descriptive requirement names. During later implementation, each task must reference the capability and requirement it satisfies. When a source behavior differs from a requirement, the implementation task records the gap rather than changing the requirement implicitly.

Primary evidence locations are:

| Area | Evidence |
| --- | --- |
| Public view and realtime behavior | `project/quarkus-java/src/main/resources/META-INF/resources/`, `SeatResource`, `SeatWebSocket` |
| State lifecycle and analytics | `SeatRepository`, `HistoryRepository`, model and DTO classes |
| Administration and login | `DashboardResource`, `UserResource`, dashboard client code |
| Sensor ingestion | `SensorService`, `application.properties`, MQTT documentation |
| Device behavior | `project/C_Pi_Movement/C_PI/main.cpp`, wiring documentation |
| Deployment | `pom.xml`, `Dockerfile`, `docker-compose.yaml`, `application.properties` |
| Product intent | project proposal, use-case diagram, UI sketches, Figma design |
| Alternative hardware | `documentation/ProofofConcept/ProofOfConcept.md` |

### Decision: Use sequential artifact ownership across threads

Each continuation thread must read `proposal.md`, this design, all completed specs, and `tasks.md` before editing. Threads work on the same change sequentially, keep requirement names stable, run strict validation, and leave a handoff stating artifacts changed, decisions made, remaining tasks, and validation status.

If work must run in parallel, each author uses an isolated worktree and an integration thread reconciles the artifacts before validation.

## Risks / Trade-offs

- **The baseline intentionally exceeds current implementation security and durability** -> Keep source-code work in later apply changes and trace every gap through tasks and tests.
- **The PIR timeout can report a stationary occupied seat as free** -> Require periodic occupied refresh and allow later calibration of the inactivity duration.
- **Retained MQTT messages can create stale occupancy** -> Require an explicit freshness policy and tests covering reconnect and retained delivery.
- **Adding `UNKNOWN` requires UI and API changes** -> Preserve a compatibility mapping during migration and never map unknown to free.
- **QR entry and server-side sessions are documented intent rather than complete current behavior** -> Treat them as target baseline requirements and identify their implementation gaps in the task plan.
- **Historical data currently lacks an explicit start column** -> Derive it during migration, validate non-negative durations, and add explicit storage when implementation begins.
- **A large baseline creates substantial implementation work** -> Execute tasks by capability and validate cross-capability journeys after each group.
- **Historical artifacts contain deprecated communication concepts** -> Allow those terms only in the proposal non-goal and this exclusion record; exclude them from specifications and implementation tasks.

## Migration Plan

1. Review and approve the proposal, design decisions, and eight capability deltas.
2. Archive the documentation-only change to establish the durable main specifications.
3. Create smaller implementation changes per capability or tightly coupled capability group.
4. Implement compatibility adapters for boolean state and existing MQTT payloads before changing external representations.
5. Migrate persistence non-destructively, including active-interval and history data validation.
6. Introduce server-side authorization before exposing administrative behavior beyond a controlled environment.
7. Remove fixed-seat assumptions and reconcile analytics against catalog-driven test fixtures.
8. Roll out device refresh and retained-message handling together so lifecycle timeouts remain reliable.
9. Validate the end-to-end public, sensor, administrative, analytics, restart, and recovery journeys before production use.

Rollback for a later implementation change must restore the prior application version without rolling back already committed durable data. Database migrations therefore need backward-compatible deployment steps or an explicit restore procedure. This planning-only change itself is rolled back by reverting its OpenSpec artifacts before archival.

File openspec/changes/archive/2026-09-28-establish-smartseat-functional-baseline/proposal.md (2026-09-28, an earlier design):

# Proposal

## Why

SmartSeat has working software, device firmware, design material, and project documentation, but it has no durable OpenSpec requirements that define the intended product behavior. A functional baseline is needed before agentic implementation can safely extend or correct the system without treating implementation quirks, prototypes, or deprecated ideas as requirements.

## What Changes

- Establish a traceable functional baseline for public seat availability, seat and location data, occupancy state transitions, sensor ingestion, administration, analytics, device behavior, and runtime operation.
- Distinguish confirmed product behavior from current implementation details, prototype alternatives, and unresolved product decisions.
- Define normal, boundary, failure, recovery, security, and persistence scenarios for each capability.
- Record shared terminology, personas, system boundaries, state semantics, and cross-capability decisions in one design artifact.
- Provide specification-authoring and validation tasks that can be completed sequentially across separate threads without changing application code.
- **BREAKING (product scope)**: Deprecate and exclude direct communication, chat, messaging, announcements, and notifications between teachers and students. Historical proposal text and UI designs that depict these functions are evidence of removed scope only and do not define current or future requirements.
- Treat Tuya, ultrasonic, NFC, and other proof-of-concept hardware alternatives as non-baseline options unless a later product decision explicitly adopts them.

## Capabilities

### New Capabilities

- `seat-availability`: Public discovery of free and occupied seats through map, list, filtering, counts, current occupancy information, and live updates.
- `seat-catalog-and-locations`: Seat identity, naming, location metadata, catalog constraints, and administrative maintenance of that data.
- `seat-state-lifecycle`: Authoritative free and occupied state transitions, occupancy timing, inactivity release, manual correction, history creation, and update broadcasts.
- `sensor-ingestion`: MQTT message contract, device-to-seat mapping, validation, duplicate and stale signal handling, and ingestion failure behavior.
- `administration-and-access-control`: Administrator authentication, authorization, session behavior, protected operations, seat renaming, and timeout configuration.
- `history-and-analytics`: Occupancy interval history, per-seat averages, daily counts, hourly utilization, leaderboard behavior, and analytics edge cases.
- `device-operation`: Raspberry Pi Pico startup, connectivity, motion sensing, message publication, reconnection, diagnostics, wiring, and failure behavior.
- `runtime-and-deployment`: Application, database, MQTT, logging, configuration, persistence, startup, health, recovery, and deployment requirements.

### Modified Capabilities

None. The project has no existing durable OpenSpec capabilities.

## Impact

- Adds planning artifacts under `openspec/changes/establish-smartseat-functional-baseline/` and, after review and archival, new durable specifications under `openspec/specs/`.
- Establishes contracts for the Quarkus REST and WebSocket interfaces, PostgreSQL persistence, MQTT ingestion, browser interfaces, and Raspberry Pi Pico firmware.
- Identifies existing implementation behavior that requires later product decisions or implementation changes, including ambiguous status semantics, timeout-based release, hard-coded seat counts, client-only dashboard gating, destructive schema initialization, and analytics aggregation rules.
- Does not modify Java, JavaScript, HTML, CSS, C/C++, database, container, or device code. Implementation work requires a separate apply request after the planning artifacts are reviewed.

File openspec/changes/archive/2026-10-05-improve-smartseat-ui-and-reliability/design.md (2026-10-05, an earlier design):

# Design

## Context

See `proposal.md` for motivation. The public UI is a static HTML/CSS/JavaScript application backed by Quarkus REST resources and a WebSocket seat snapshot. It currently renders two floors through one reused map, indexes five fixed DOM markers, builds five fixed chart series, serializes active timing as timezone-free `LocalDateTime`, and compensates in the browser with a hard-coded `+02:00` offset. The administration page uses a fixed-height, three-column grid with overflow hidden.

The existing OpenSpec baseline already requires catalog-sized behavior, additive hourly utilization, consistent time handling, and correct interval lifecycle semantics. This change aligns the implementation with that baseline and adds the tested presentation behavior.

## Goals / Non-Goals

**Goals:**

- Establish one timezone-safe representation for active interval instants.
- Render floor and analytics views from catalog data rather than seat-number assumptions.
- Keep public and administrative controls usable with pointer, keyboard, and narrow screens.
- Make analytics understandable and inspectable independently of relative visual size.
- Preserve the existing public endpoints and Map/List/Chart information architecture.

**Non-Goals:**

- Redesign the physical floor-plan artwork.
- Replace Chart.js or introduce a frontend framework.
- Add new floors, seats, authentication architecture, or analytics metrics.
- Change inactivity-release policy from timeout-based release.
- Treat the administration dashboard as a public view.

## Decisions

### 1. Use absolute instants at the lifecycle and API boundary

Represent `occupiedSince` and in-memory last-observed values with an absolute time type such as `Instant`; serialize the DTO value in ISO 8601 UTC form. The browser parses the supplied value directly and clamps a transient negative difference to zero while awaiting a corrected snapshot.

This removes dependence on the JVM timezone, browser timezone, and daylight-saving offset. Keeping `LocalDateTime` and documenting an assumed server zone was rejected because it would preserve ambiguity and the current two-hour failure mode. Appending a computed browser offset was rejected because the server value still would not identify an instant.

Use an injectable clock for lifecycle calculations where practical so transition and timezone tests can be deterministic. Preserve the original interval start on repeated occupied observations and update only last-observed time.

### 2. Render a catalog-driven floor-map collection

Build the map view by grouping the WebSocket snapshot by floor, ordering the known floors naturally, and generating one labeled map panel per group. At the current two-floor deployment, the responsive grid places `1.OG` left and `2.OG` right; below the minimum readable panel width it changes to one column.

Each seat receives normalized map coordinates in catalog data. Marker elements are generated from stable seat IDs, carry readable labels and state text, and support focus/click as well as hover. A seat without valid coordinates is omitted only from graphical placement and remains present in the list/text representation with a visible data-quality indication.

Reusing the existing floor-selector cards was rejected because it preserves hidden context and unnecessary interaction. Duplicating fixed markup for two floors was rejected because it conflicts with catalog-sized behavior.

### 3. Preserve Map/List/Chart navigation with explicit state

Use buttons with stable view identifiers. The selected control receives an active class and `aria-pressed="true"` (or an equivalent single-selection pattern); inactive controls receive the corresponding false state. View activation updates both visual state and content visibility without changing the existing default Map view.

Removing Map/List/Chart was rejected because the views answer different user questions. Only the obsolete floor-selection controls are removed.

### 4. Keep hourly utilization as the chart metric

The durable specification already defines hourly utilization, so the chart remains a line chart of occupied time per seat-hour rather than switching to completed-visit counts. The backend sums every interval overlap per seat-hour and clamps the total to 3600 seconds before converting it to a percentage.

The response and datasets are built from catalog seats and explicit hour keys instead of assuming that seat 1 supplies all labels or that identifiers are contiguous. The canvas labels utilization as percent, uses 0-100 bounds, and configures index-based, non-intersecting interaction with usable point hit areas. A synchronized textual table exposes the same values and serves as the non-canvas representation. An explicit empty state replaces a zero-only chart when there is no data.

A logarithmic scale was rejected because utilization has a bounded, meaningful linear percentage scale. Persistent labels on every point were rejected because 24 hours across multiple seats would become unreadable.

### 5. Reflow the dashboard instead of scaling it down

Replace the fixed viewport/hidden-overflow contract with a page that can scroll. Use a responsive grid with three columns on wide screens, two columns at laptop widths, and one column on narrow screens. Panels use content-driven heights; the leaderboard receives a bounded internal scroll region only when its entries exceed the allocated panel height. Form rows wrap and controls retain usable widths.

Shrinking the existing three columns was rejected because the presentation demonstrates that it makes labels and controls unreadable. Making every panel independently scrollable was rejected because nested scrolling would harm phone usability.

### 6. Make unchanged renames idempotent

Normalize the submitted name once. If it equals the target seat's normalized current name, return the current catalog as success without issuing an update or broadcast. Otherwise, test uniqueness against other seat IDs and return conflict only for another owner. Server-side handling remains authoritative even if the client also disables a no-change save.

### 7. Verify behavior at service and viewport boundaries

Add backend tests for transition start time, repeated observations, differing timezone environments, overlap summation/capping, dynamic seat identifiers, unchanged rename, and true duplicate rename. Use repeatable browser checks at representative wide, laptop, and phone viewport widths for dual-map order, active navigation, keyboard-accessible details, chart textual values, dashboard reflow, and leaderboard reachability.

## Risks / Trade-offs

- [Changing persisted timestamp types can require database conversion outside the current drop-and-create development setup] -> Define the intended SQL conversion before production deployment and keep rollback instructions for the previous column representation.
- [Existing seats do not yet have per-seat map coordinates] -> Seed coordinates for all current seats and keep unplaceable seats available in the list rather than guessing a position.
- [A data table duplicates chart content and can become large] -> Keep it semantically available, allow users to reveal/collapse it visually, and scope it to the selected date.
- [WebSocket updates currently trigger repeated analytics requests] -> Load analytics when the Chart view/date changes or debounce invalidation so seat heartbeat traffic does not recreate the chart unnecessarily.
- [Two internal scroll regions can be awkward on touch devices] -> Prefer page scrolling on narrow screens and reserve leaderboard-only scrolling for layouts with a bounded panel height.

## Migration Plan

1. Add map coordinates for the current catalog and introduce the absolute timestamp representation with a compatible database conversion where persistent data is retained.
2. Update backend DTOs, lifecycle calculations, rename behavior, and analytics aggregation; verify endpoint contracts before changing the clients.
3. Deploy the catalog-driven public views and responsive administration styles together with their backend contract changes.
4. Run the automated backend suite and the viewport/accessibility check matrix against current seat and history data.
5. Roll back application and schema changes together if timestamp conversion or client compatibility fails; the existing endpoints and navigation names remain stable.

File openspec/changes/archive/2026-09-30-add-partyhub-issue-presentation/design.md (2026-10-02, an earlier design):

# Design

## Context

See `proposal.md` for motivation and `specs/partyhub-issue-presentation/spec.md` for the behavioral contract.

The current PartyHub report is a German Markdown file that references three images and six filenames for five unique recordings. The two fourth-recording files have identical hashes; despite its `.mp4` extension, `fehler4.mp4` contains WebM data. The unique video payload is about 44.2 MiB before base64 encoding, so a fully embedded presentation will be approximately 60 MiB before browser decoding overhead. The duplicate-email screenshot contains an email address and a verification URL or token that must not be distributed unchanged.

## Goals / Non-Goals

**Goals:**

- Produce one durable HTML file that can be copied, opened offline, and presented without installation.
- Give the findings a coherent German, risk-oriented narrative rather than reproducing the Markdown layout verbatim.
- Keep each recording or screenshot directly associated with the finding it demonstrates.
- Make the presentation practical at a projector resolution while retaining usable narrow-screen behavior.
- Ensure that the actual embedded media payload, not merely its visual presentation, is free of sensitive account data.

**Non-Goals:**

- Change or fix PartyHub itself.
- Convert the presentation to `.pptx` or require PowerPoint.
- Add a permanent build system, package manifest, server, or runtime dependency to the repository.
- Preserve the misspellings and formatting defects of the source report when clearer German wording can express the same finding.

## Decisions

### Use an inlined Reveal.js browser bundle

Use Reveal.js for slide layout, keyboard and touch navigation, controls, progress, scaling, transitions, and presentation lifecycle events. Inline the required minified JavaScript and CSS in the final document and retain the applicable Reveal.js license notice. Configure the deck for 16:9 content, visible controls and progress, keyboard and touch navigation, URL hashes, and restrained transitions.

Reveal.js is preferred over a custom slide engine because it supplies proven presentation behavior and responsive scaling. Impress.js was considered, but its spatial canvas effects do not improve this evidence-led deck and would require more custom accessibility and navigation work. A hand-written engine was rejected because the user explicitly requested a JavaScript presentation library and because it would recreate mature behavior unnecessarily.

### Deliver exactly one repository artifact

The final repository artifact is `documentation/FehlersuchePartyfinder/PartyHub-Issues-Presentation.html`. All CSS, JavaScript, images, fonts used by the deck, and media payloads are embedded. No runtime URL points to a CDN, local sibling file, or remote font.

Temporary tooling or sanitized media derivatives may be used during generation, but they are not retained as required presentation dependencies. This keeps the requested distribution model while allowing irreversible media redaction before encoding.

An HTML file plus adjacent assets was rejected because it would be easier to break when copied. Runtime CDN loading was rejected because it violates offline operation.

### Embed media as base64 and materialize videos lazily

Images use base64 data URLs. Each unique video is stored once as base64 inside a non-executable data block in the HTML. Presentation JavaScript converts a video's data to a Blob URL when its slide is first activated and attaches that URL to the `<video>` element. Videos expose native controls, use `preload="metadata"`, and never autoplay. Blob URLs are revoked when the page unloads.

Lazy materialization limits the amount of decoded video data retained before it is needed. Direct data URLs on every `<video>` element were considered but would make initial media parsing and memory use less predictable. External media files were rejected because the output must remain self-contained.

The identical `fehler4.mp4` and `fehler4.webm` payload is included once with the WebM MIME type. The other four recordings retain their MP4 MIME type unless implementation-time browser validation proves a source codec incompatible, in which case a compatible sanitized transcode is embedded.

### Use a fourteen-slide risk narrative

The deck uses this structure:

1. Title and purpose
2. Executive summary with the 3/2/5 risk distribution
3. High-risk section introduction
4. Party navigation authentication bypass with `fehler1.mp4`
5. Account navigation authentication bypass with `fehler2.mp4`
6. Notification navigation authentication bypass with `fehler3.mp4`
7. Medium-risk section introduction
8. Mobile login scaling with `Skalierungsfehler.jpeg`
9. Second-tab login failure with `fehler4.webm`
10. Low-risk section introduction and expired-party finding
11. Email-verification contrast with `blackFont.png`
12. Duplicate registration email with a sanitized `doppelt.png` derivative
13. Party-page spacing and inconsistent profile navigation with `Fehler5.mp4`
14. Recommended remediation order and conclusion

Each detailed finding slide uses a consistent pattern: risk badge, affected interaction, observed behavior, impact, and evidence. The high-risk label from the source is preserved even though implementation cannot independently prove exploitability from the report alone.

### Redact before embedding rather than hiding in CSS

Audit every screenshot and recording for email addresses, verification URLs or tokens, authentication secrets, and identifying account data. Create sanitized raster or video derivatives before base64 encoding. Redaction must replace or remove the underlying pixels or frames; CSS blurs, masks, clipping, or overlays alone are insufficient because the original bytes would remain extractable from the HTML.

The duplicate-email screenshot is known to require sanitization. Other media is treated as unverified until visually reviewed during implementation. If a recording contains sensitive data, crop or transcode it with irreversible masking while retaining the behavior needed as evidence.

### Add presentation-specific controls and accessibility cues

Use Reveal.js navigation plus a small custom fullscreen control backed by the browser Fullscreen API. Provide meaningful German headings, media labels, alternative text for screenshots, visible focus states, sufficient color contrast, and reduced-motion behavior via `prefers-reduced-motion`. Pause any playing video when its slide is left so audio does not continue across findings.

## Risks / Trade-offs

- **Large output and memory use** -> Expect roughly 60 MiB of HTML; lazy video materialization, deduplication, and metadata-only preload reduce startup and memory pressure without dropping evidence.
- **Browser codec differences** -> Validate every recording in at least current Chromium and Firefox; transcode only incompatible media to a broadly supported format while preserving evidence.
- **Sensitive details could survive superficial masking** -> Sanitize media before encoding and inspect the final HTML payload and rendered output rather than relying on CSS concealment.
- **Base64 generation is error-prone** -> Compare embedded payload counts and decoded hashes against the intended sanitized sources, and test every media control offline.
- **A single generated file is difficult to review in a text diff** -> Keep all human-readable slide markup and presentation styles organized before the large media blocks, add clear comments, and validate behavior through scripted structural checks plus browser review.
- **The source wording is sometimes ambiguous or misspelled** -> Improve language without inventing reproduction steps, and visibly distinguish observed behavior from inferred impact.

## Migration Plan

1. Audit and sanitize the source media in temporary working files.
2. Build the German slide markup and inlined presentation runtime.
3. Embed and deduplicate the sanitized media payloads.
4. Run structural, privacy, offline, responsive, navigation, and playback verification.
5. Add the single completed HTML file at the proposed path.

Rollback consists of removing the new HTML file; no existing application or documentation behavior is migrated.

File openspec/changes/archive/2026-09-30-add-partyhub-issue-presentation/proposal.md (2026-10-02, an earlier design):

# Proposal

## Why

The PartyHub issue findings currently exist as a Markdown report with separate screenshots and recordings, which is inconvenient to present and distribute. A self-contained, presentation-style HTML document will make all findings easy to review offline while preserving the supporting evidence and risk classification.

## What Changes

- Add a German presentation covering all ten PartyHub findings from `documentation/FehlersuchePartyfinder/FehlersuchePartyfinder.md`.
- Organize the findings into high-, medium-, and low-risk sections with an executive summary and remediation priorities.
- Include the five unique issue recordings and the relevant screenshots as embedded presentation evidence.
- Deliver the presentation as one offline HTML file with no required CDN, network connection, or adjacent asset files.
- Provide PowerPoint-like keyboard, on-screen, progress, and fullscreen presentation controls.
- Prevent sensitive account details, email addresses, and verification tokens from appearing in distributed evidence.

## Capabilities

### New Capabilities

- `partyhub-issue-presentation`: Defines the content, evidence handling, offline packaging, privacy, and presentation behavior of the PartyHub issue presentation.

### Modified Capabilities

None.

## Impact

- Adds `documentation/FehlersuchePartyfinder/PartyHub-Issues-Presentation.html` as the distributable presentation.
- Uses the existing Markdown report, three screenshots, and five unique recordings as source material.
- Introduces an embedded Reveal.js runtime and presentation styling inside the HTML deliverable.
- Does not change the SmartSeat application, PartyHub application, APIs, or existing OpenSpec capabilities.

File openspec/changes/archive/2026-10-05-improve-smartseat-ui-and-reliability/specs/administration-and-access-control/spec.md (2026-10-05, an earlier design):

# Spec Delta

## MODIFIED Requirements

### Requirement: Inactivity duration administration
An authenticated administrator SHALL be able to read and change the inactivity duration, the administrative interface SHALL identify the value as seconds, and the system SHALL accept only whole-second values greater than ten.

#### Scenario: Display duration value
- **WHEN** an authenticated administrator views the inactivity-duration control
- **THEN** the interface identifies the value and accepted input unit as seconds

#### Scenario: Valid duration update
- **WHEN** an administrator submits a whole-second duration greater than ten
- **THEN** the new duration is persisted and used for subsequent timeout evaluations

#### Scenario: Invalid duration update
- **WHEN** an administrator submits a duration of ten seconds or less or a non-integer value
- **THEN** the system rejects the request and preserves the existing duration

## ADDED Requirements

### Requirement: Responsive administrative workspace
The administrative workspace SHALL keep all authorized controls and results readable, reachable, and operable at supported desktop, laptop, and phone viewport sizes.

#### Scenario: Medium viewport
- **WHEN** the dashboard no longer fits its full wide-screen column layout
- **THEN** panels reflow without compressing inputs or buttons below a usable size

#### Scenario: Narrow viewport
- **WHEN** an administrator uses the dashboard on a phone-sized viewport
- **THEN** panels form a readable single-column flow and the page can scroll to every control

#### Scenario: Leaderboard exceeds available height
- **WHEN** leaderboard entries exceed the panel's available height
- **THEN** the entries can be scrolled without being clipped or covering other dashboard controls

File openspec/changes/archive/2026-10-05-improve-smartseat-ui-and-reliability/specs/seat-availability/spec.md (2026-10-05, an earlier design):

# Spec Delta

## MODIFIED Requirements

### Requirement: Location filtering and counts
The system SHALL present every configured floor in a separately labeled map in the default public map view, SHALL allow a location-specific entry point to focus the requested location, and SHALL calculate each displayed free-seat count from the same seat dataset shown for that location.

#### Scenario: Default multi-floor overview
- **WHEN** a user opens the default public map view and the catalog contains seats on `1.OG` and `2.OG`
- **THEN** the system shows labeled maps for `1.OG` and `2.OG` simultaneously with the seats and free-seat count belonging to each floor

#### Scenario: Filter by floor
- **WHEN** a user or location-specific entry point focuses a configured floor
- **THEN** the interface emphasizes that floor and its count while preserving access to the complete multi-floor overview

#### Scenario: Location-specific focus
- **WHEN** a user opens the availability view through a valid location-specific entry point
- **THEN** the requested location is focused without mislabeling or removing the other configured location data

#### Scenario: Location has no seats
- **WHEN** a configured floor has no seats
- **THEN** its labeled map shows an empty state and a free-seat count of zero without reporting an error

### Requirement: Current occupancy duration
The system SHALL show the non-negative elapsed duration of the current occupancy interval for an occupied seat, calculated from an unambiguous recorded interval start and the current time, and SHALL omit that duration for free or unknown seats.

#### Scenario: Newly occupied seat
- **WHEN** a free seat becomes occupied and a user inspects it immediately
- **THEN** the displayed duration begins near zero and does not include a client/server timezone offset

#### Scenario: Occupied seat duration
- **WHEN** a user inspects a seat with an active occupancy interval
- **THEN** the displayed non-negative elapsed duration is derived from the recorded absolute interval start and the current instant

#### Scenario: Repeated occupancy update
- **WHEN** another occupancy observation is accepted for an already occupied seat
- **THEN** the displayed duration continues from the original interval start instead of restarting

#### Scenario: Seat becomes free
- **WHEN** an occupied seat transitions to free
- **THEN** the public view stops displaying an active occupancy duration for that seat

## ADDED Requirements

### Requirement: Public view navigation state
The system SHALL keep the Map, List, and Chart views available and SHALL visibly and programmatically identify which view is active.

#### Scenario: Switch public view
- **WHEN** a user activates Map, List, or Chart
- **THEN** only the selected view is presented as current and its navigation control is visually distinct from the other controls

#### Scenario: Keyboard navigation
- **WHEN** a keyboard user moves through and activates the public navigation controls
- **THEN** focus remains visible and the active view can be determined without relying only on color

### Requirement: Responsive multi-floor presentation
The public availability interface SHALL keep floor labels, seat states, counts, navigation, and seat details readable and reachable across supported viewport sizes.

#### Scenario: Wide viewport
- **WHEN** the viewport has sufficient horizontal space
- **THEN** the `1.OG` map is presented to the left of the `2.OG` map

#### Scenario: Narrow viewport
- **WHEN** the two maps cannot retain their minimum readable size side by side
- **THEN** the maps stack vertically without clipping content or requiring horizontal page scrolling

#### Scenario: Seat details without hover
- **WHEN** a user cannot or does not use pointer hover
- **THEN** the seat name, state, and active duration remain available through focus, activation, or equivalent visible text

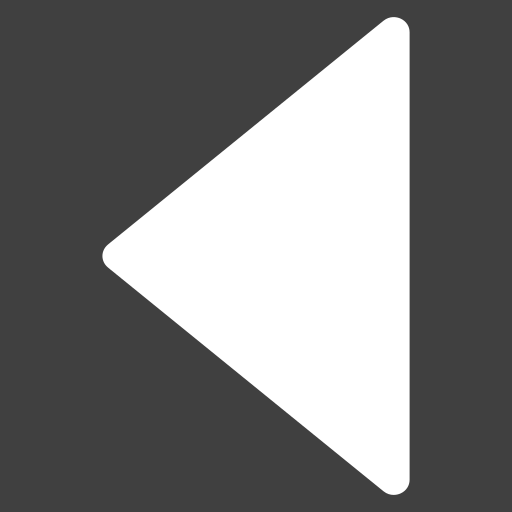
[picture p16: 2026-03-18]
project/quarkus-java/src/main/resources/META-INF/resources/assets/img/selected.png

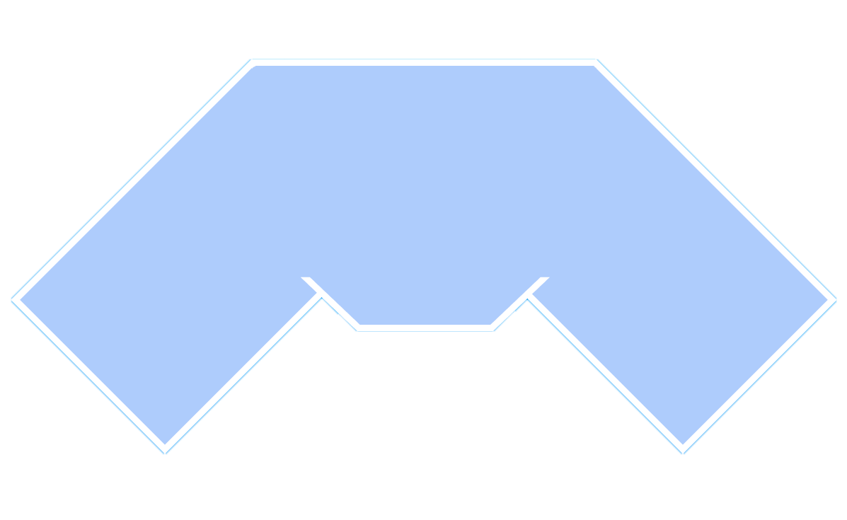
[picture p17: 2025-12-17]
project/quarkus-java/src/main/resources/META-INF/resources/assets/img/map2.png

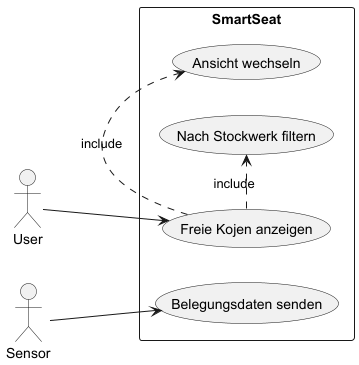
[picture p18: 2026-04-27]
documentation/UseCase/SmartSeat.png

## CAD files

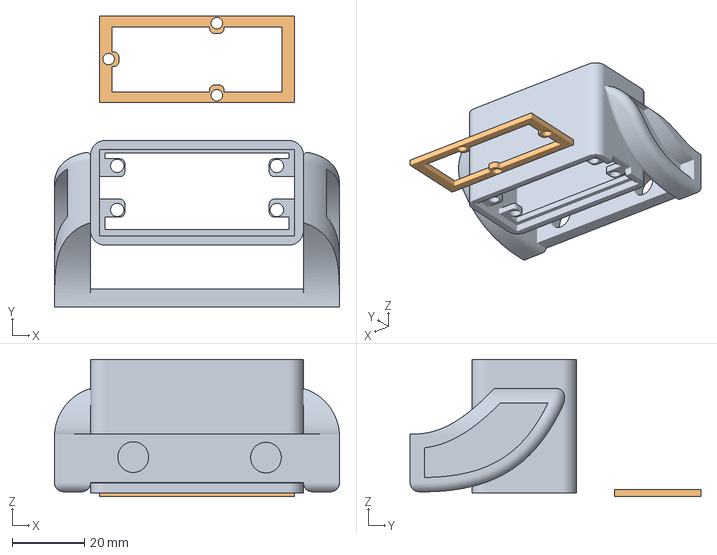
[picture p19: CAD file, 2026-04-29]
documentation/Gehäuse/SmartseatGehäuseMkii.3mf
79.0 x 80.6 x 38.0 mm
Gehäuse
Sensorhalterung

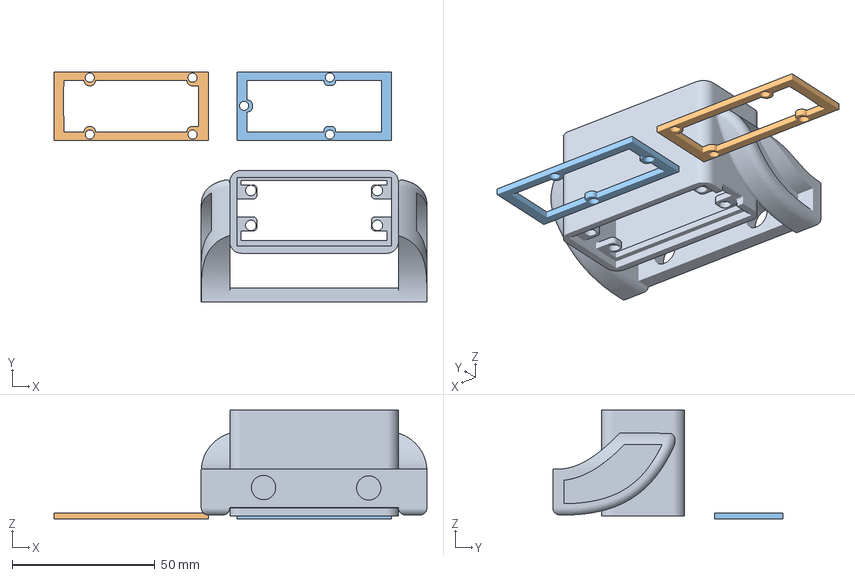
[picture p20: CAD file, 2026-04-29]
documentation/Gehäuse/Smartseat-GehäuseMkiii.3mf
130.5 x 80.6 x 38.0 mm
Gehäuse
Sensorhalterung Joy-it (1)
Sensorhalterung Seedstudio

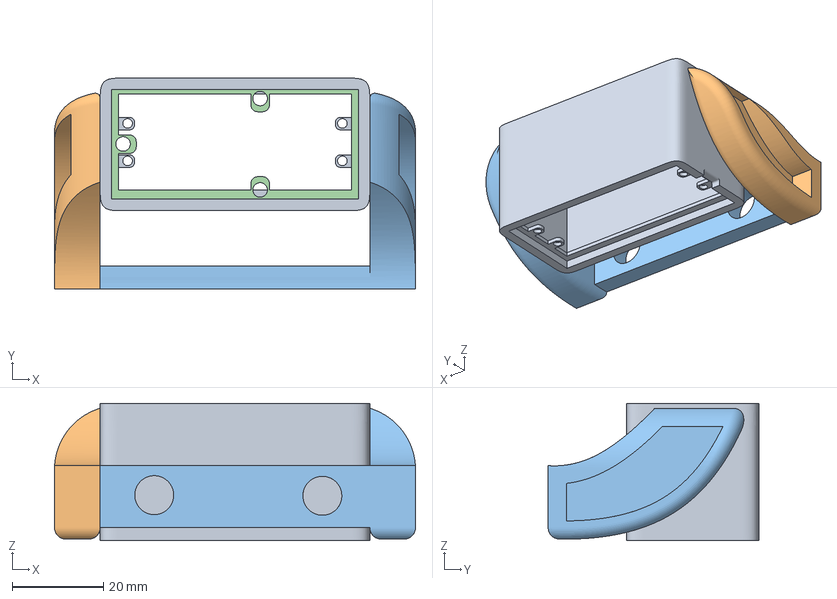
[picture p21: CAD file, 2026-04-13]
documentation/Gehäuse/Smartseat-Gehäuse.3mf
79.0 x 46.1 x 30.0 mm
Gehäuse
Körper11
Körper9
Sensorhalterung

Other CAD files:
documentation/Gehäuse/Smartseat2.f3d

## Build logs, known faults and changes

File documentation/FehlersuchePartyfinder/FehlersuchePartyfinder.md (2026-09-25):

# Fehlersuche auf der Seite von Partyfinder

## High Risk

<ul>
<li><span style="font-size: 2.5vh;">Sobald auf eine Party gecklickt wird, kommt man zu einem anmeldefenster. Wenn man jedoch einen Schritt zurückgeht, wird die Party ohne Anmeldung angezeigt.</span></li>
<br>
<video width="320" height="240" controls>
  <source src="./vid/fehler1.mp4" type="video/mp4">
</video>
<br><br>
<li><span style="font-size: 2.5vh;">Sobald auf einen Account gecklickt wird, kommt man zu einem anmeldefenster. Wenn man jedoch einen Schritt zurückgeht, wird die Party ohne Anmeldung angezeigt.</span></li>

<br>

<video width="320" height="240" controls>
  <source src="./vid/fehler2.mp4" type="video/mp4">
</video>
<br><br>

<li><span style="font-size: 2.5vh;">Sobald auf Notifications gecklickt wird, kommt man zu einem anmeldefenster. Wenn man jedoch einen Schritt zurückgeht, wird die Party ohne Anmeldung angezeigt.</span></li>
<br>

<video width="320" height="240" controls>
  <source src="./vid/fehler3.mp4" type="video/mp4">
</video>
</ul>

## Medium Risk

<ul>
<li><span style="font-size: 2.5vh;">Wenn man sich auf einem Handy anmelden will, hat man das Problem, dass das Login-OVerlay viel zu klein ist.</span></li>
<br>

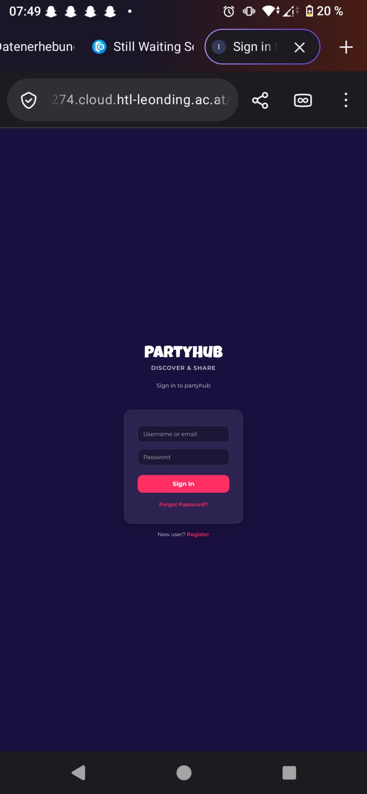
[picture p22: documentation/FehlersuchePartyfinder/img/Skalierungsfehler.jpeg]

<br><br>
<li><span style="font-size: 2.5vh;">Wenn man einen zweiten Tab öffnet, kommt es zu einen Loginfehler. </span></li>
<br>
<video width="320" height="240" controls>
  <source src="./vid/fehler4.webm" type="video/webm">
</video>
</ul>

## Low Risk

<ul>
<li><span style="font-size: 2.5vh;">Sobald eine Party vergangen ist, wird sie trotzdem angezeigt</span></li>
<br>
<li><span style="font-size: 2.5vh;">Wenn man auf das Fenster zur E-Mail verifycation kommt, dann wird der Text "You need to verify your email address to activate your account." in schwarzer Farbe auf lila Hintergrund angezeigt.</span></li>

<br>

>Contrast Guidlines nicht eingehalten!

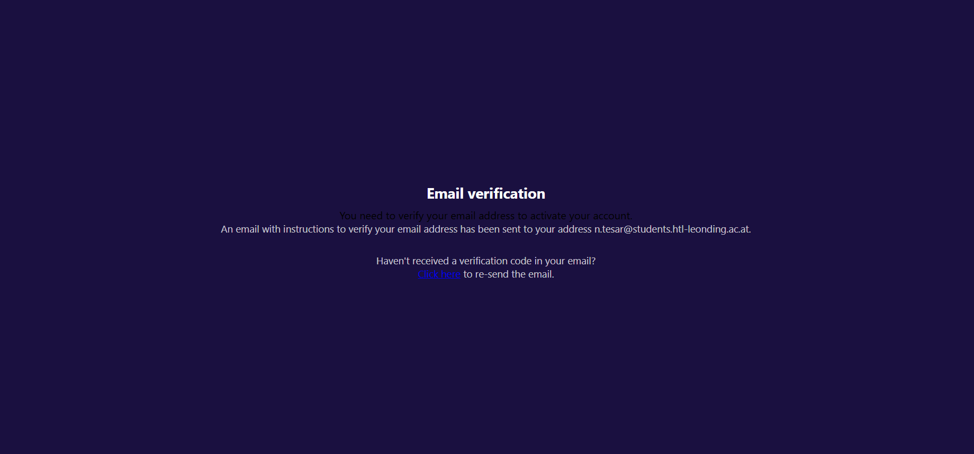
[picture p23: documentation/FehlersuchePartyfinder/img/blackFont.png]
blackFont


<li><span style="font-size: 2.5vh;">Beim registrieren wird die Nachricht doppelt gesendet</span></li>
<br>

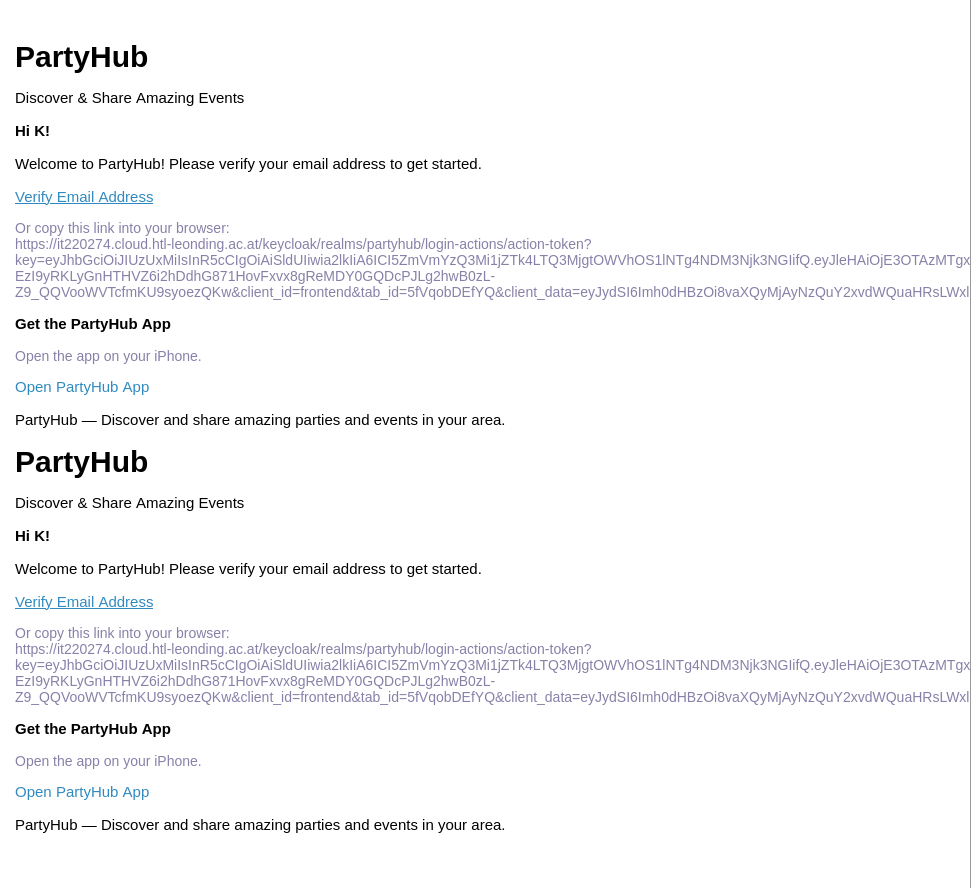
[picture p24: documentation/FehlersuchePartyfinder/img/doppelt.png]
doppelt


</ul>

<ul>
<li><span style="font-size: 2.5vh;">Bei der Partyunterseite ist über dem "Create new Party" Knopf zu wenig Platz.</span></li>
<br>
<li><span style="font-size: 2.5vh;">Navbar ist bei der Profilseiten nicht gleich groß.</span></li>
<br>
<video width="320" height="240" controls>
  <source src="./vid/fehler5.mp4" type="video/mp4">
</video>

</ul>

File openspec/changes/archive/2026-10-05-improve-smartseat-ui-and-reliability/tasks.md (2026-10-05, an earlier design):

# Tasks

## 1. Catalog and Time Contracts

- [x] 1.1 Add normalized per-seat map coordinates to the persisted catalog and seat DTO, seed valid coordinates for the five current seats, and verify repository/resource tests return each seat's floor and placement without assuming contiguous IDs.
- [x] 1.2 Replace timezone-free active interval and last-observed values with absolute instants using an injectable clock, preserve the original interval start on repeated occupied observations, and verify deterministic lifecycle tests cover first occupancy, repeated occupancy, inactivity release, and a daylight-saving boundary.
- [x] 1.3 Serialize active interval starts with `Z` or an explicit offset in REST/WebSocket snapshots and verify a contract test parses the same instant under different JVM timezone settings.

## 2. Backend Behavior Corrections

- [x] 2.1 Rework hourly utilization to enumerate catalog seats, sum every interval overlap per seat-hour, clamp each total to 3600 seconds, and verify tests cover multiple intervals, an hour boundary, a capped overlap, a non-contiguous seat ID, and a no-data date.
- [x] 2.2 Normalize rename input, return success without an update for the target seat's unchanged name, and conflict only when another seat owns the name; verify resource tests cover unchanged, unique, duplicate, blank, and unknown-seat requests.
- [x] 2.3 Ensure public seat snapshots and analytics responses expose catalog display names and all configured identifiers, and verify adding a test seat requires no frontend-specific or aggregation code change.

## 3. Public Map, List, and Navigation

- [x] 3.1 Replace the single map and floor-selector markup with a catalog-driven floor-map container while preserving Map, List, and Chart controls; verify the rendered default order places `1.OG` before `2.OG` and contains no obsolete floor-selector controls.
- [x] 3.2 Generate floor panels, free counts, seat markers, and list entries from snapshot data and normalized coordinates, with a textual fallback for invalid placement; verify fixtures with extra and non-contiguous seat IDs render without missing or placeholder seats.
- [x] 3.3 Add visible and programmatic active state to Map/List/Chart controls and keyboard-operable seat details, and verify focus, activation, current-view state, seat name, canonical state, and duration are available without pointer hover.
- [x] 3.4 Parse the server-provided occupancy instant without adding a client offset, update elapsed time from the original interval start, and verify a newly occupied fixture starts near zero in browsers configured for different timezones.
- [x] 3.5 Implement the responsive two-map layout with side-by-side wide-screen panels and vertically stacked narrow-screen panels, and verify floor labels, counts, markers, and details remain readable without horizontal page scrolling.

## 4. Analytics Presentation

- [x] 4.1 Build hourly chart labels and series from explicit response keys and catalog names, convert utilization to 0-100 percent, label both axes and the metric meaning, and verify dynamic/non-contiguous seat fixtures produce correctly named series.
- [x] 4.2 Configure index-based non-intersecting chart interaction with usable hit areas and add a synchronized textual value table, then verify all seat values for an hour are obtainable by pointer and keyboard even when their sizes differ substantially.
- [x] 4.3 Show an explicit no-data state and avoid rebuilding the chart on every unrelated WebSocket snapshot, and verify an empty date hides the misleading chart while relevant date/data changes refresh it once.

## 5. Administrative Dashboard

- [x] 5.1 Label the inactivity duration control and success feedback in seconds, keep no-change rename saves from showing an error, and verify the visible wording and unchanged-name flow match the API result.
- [x] 5.2 Replace fixed viewport heights and hidden page overflow with a responsive three-, two-, and one-column dashboard grid, allow form rows to wrap, and verify every panel and control is reachable at wide, laptop, and phone widths.
- [x] 5.3 Add bounded leaderboard scrolling for constrained desktop/laptop panels while preferring page scrolling on narrow screens, and verify a leaderboard longer than the viewport does not clip entries or cover neighboring controls.

## 6. Integrated Verification

- [x] 6.1 Run the Quarkus test suite from `project/quarkus-java` and verify all existing and new lifecycle, API, analytics, and rename tests pass.
- [x] 6.2 Run the repeatable browser check matrix at approximately 1440x900, 1024x768, and 390x844 with keyboard-only navigation, and verify the dual-map order, active navigation, timer, chart/table values, dashboard reflow, and leaderboard reachability satisfy the delta specs.
- [x] 6.3 Validate the completed OpenSpec change with strict validation and verify no proposal capability lacks its matching delta spec.

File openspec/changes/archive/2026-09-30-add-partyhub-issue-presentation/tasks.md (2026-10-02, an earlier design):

# Tasks

## 1. Prepare Source Content and Evidence

- [x] 1.1 Convert the ten Markdown findings into a German content inventory with three high-, two medium-, and five low-risk entries, and verify every source list item is mapped to exactly one presentation finding.
- [x] 1.2 Hash and classify the six recording filenames, retain only the five unique payloads, treat the fourth recording as WebM, and verify the duplicate hash is not included twice.
- [x] 1.3 Visually audit all screenshots and recordings for account identifiers, email addresses, verification URLs or tokens, secrets, and personal data, and verify the audit records a sanitization decision for every media item.
- [x] 1.4 Create temporary irreversible sanitized derivatives for every media item that needs redaction, including `doppelt.png`, and verify sensitive source pixels or frames cannot be recovered from each derivative.
- [x] 1.5 Verify every sanitized recording plays in current Chromium and Firefox, and transcode only incompatible recordings to a supported format while confirming the demonstrated issue remains visible.

## 2. Build the Self-Contained Presentation

- [x] 2.1 Create `documentation/FehlersuchePartyfinder/PartyHub-Issues-Presentation.html` with an inlined, pinned Reveal.js JavaScript and CSS bundle plus its license notice, and verify the HTML contains no runtime CDN or package dependency.
- [x] 2.2 Implement the fourteen-slide German narrative defined in `design.md`, and verify the rendered deck contains the executive summary, all ten findings, three risk sections, and the closing remediation priorities.
- [x] 2.3 Apply the PartyHub-inspired visual theme, consistent risk badges, readable typography, evidence layouts, visible focus styles, and reduced-motion rules, and verify slides remain legible in 16:9 and mobile-width viewports without horizontal page scrolling.
- [x] 2.4 Add meaningful headings, screenshot alternative text, media labels, and semantic controls, and verify keyboard focus and accessible names are visible and understandable.

## 3. Embed and Control Evidence

- [x] 3.1 Embed the three sanitized screenshots as data URLs beside their matching findings, and verify each image renders after the HTML file is copied away from the source asset directories.
- [x] 3.2 Embed each of the five unique sanitized recordings once as a base64 media data block, and verify the final HTML contains five video payloads with no duplicate fourth-recording payload.
- [x] 3.3 Implement lazy conversion of video data blocks to Blob URLs with metadata-only preload and unload cleanup, and verify videos are materialized on first slide activation and their Blob URLs are revoked when the page unloads.
- [x] 3.4 Provide native video controls, disable autoplay, and pause media when its slide is left, and verify no video starts or continues playing across a slide change without presenter action.

## 4. Presentation Interaction

- [x] 4.1 Initialize Reveal.js with keyboard, touch, on-screen controls, progress, URL hashes, 16:9 scaling, and restrained transitions, and verify next and previous actions move exactly one slide by keyboard and by visible controls.
- [x] 4.2 Add a labelled fullscreen control using the browser Fullscreen API with a graceful unsupported-state fallback, and verify the deck enters and exits fullscreen when the browser permits it.
- [x] 4.3 Add slide lifecycle handling for media and presentation state, and verify revisiting a finding restores usable controls without restarting or duplicating the embedded payload.

## 5. Validate the Deliverable

- [x] 5.1 Run structural checks that the deliverable is one HTML file, all required code and media are embedded, no external `src`, `href`, font, or network dependency remains, and verify the checks pass.
- [x] 5.2 Decode representative embedded image and video payloads and compare their hashes with the intended sanitized inputs, and verify base64 generation did not corrupt the evidence.
- [x] 5.3 Open a copied version of the HTML with network access disabled and verify all fourteen slides, styles, controls, screenshots, and five recordings work without adjacent files.
- [x] 5.4 Review the rendered deck in current Chromium and Firefox at desktop projector and mobile widths, and verify navigation, fullscreen behavior where supported, responsiveness, contrast, and every media control meet the specification scenarios.
- [x] 5.5 Inspect the final HTML source and all rendered evidence for sensitive account information, and verify no email address, verification URL or token, secret, or identifying account data is present in the distributed payload.

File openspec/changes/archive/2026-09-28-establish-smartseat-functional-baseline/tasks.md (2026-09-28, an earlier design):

# Tasks

## 1. Scope and Evidence Baseline

- [x] 1.1 Inventory the OpenSpec root, README, documentation folder, UI artifacts, relevant source, tests, configuration, firmware, and hardware models; verify the evidence areas are summarized in `design.md`
- [x] 1.2 Compare implemented behavior with documented intent and verify `design.md` records the evidence-precedence rule and the major implementation gaps
- [x] 1.3 Lock the approved product boundary and verify the proposal, design, and capability list contain no unapproved capability

## 2. Shared Functional Model

- [x] 2.1 Define stable seat identity, catalog-derived cardinality, and location semantics; verify the catalog spec covers rename, duplicate, unknown-id, non-contiguous-id, and more-than-five-seat scenarios
- [x] 2.2 Define the `FREE`, `OCCUPIED`, and `UNKNOWN` state model; verify lifecycle scenarios cover first observation, repeated observation, timeout, correction, atomic completion, and restart recovery
- [x] 2.3 Define MQTT boolean compatibility and timeout semantics; verify ingestion scenarios cover malformed, unknown, duplicate, retained, disconnected, and reconnected messages
- [x] 2.4 Define interval and time semantics; verify analytics scenarios cover averages, empty data, invalid dates, multiple intervals per hour, catalog-derived seats, and day boundaries

## 3. Capability Specifications

- [x] 3.1 Create `seat-availability` requirements and verify public access, presentation, filtering, counts, realtime recovery, duration display, and QR entry each have scenarios
- [x] 3.2 Create `seat-catalog-and-locations` and `seat-state-lifecycle` requirements and verify every requirement uses normative language and at least one scenario
- [x] 3.3 Create `sensor-ingestion` and `device-operation` requirements and verify the wire contract and Pico behavior agree on identifier and status meanings
- [x] 3.4 Create `administration-and-access-control` requirements and verify authentication, server-side authorization, expiry, logout, credential protection, configuration validation, and audit scenarios are present
- [x] 3.5 Create `history-and-analytics` requirements and verify calculations do not assume five seats or use maximum overlap in place of summed utilization
- [x] 3.6 Create `runtime-and-deployment` requirements and verify production durability, external configuration, health, logging, recovery, and environment separation are covered

## 4. Cross-Capability Review

- [x] 4.1 Review all eight specs for shared terminology and verify state names, seat identity, time zone, authorization, and error semantics are consistent
- [x] 4.2 Walk through public discovery, sensor occupancy, inactivity release, administrative correction, analytics, broker outage, application restart, and realtime reconnection; verify every step maps to at least one requirement and scenario
- [x] 4.3 Compare the proposal capability list with the eight spec paths and verify there are no missing, duplicate, or undeclared capability deltas
- [x] 4.4 Run the deprecated-scope audit and verify excluded historical concepts appear only in the proposal non-goal and design exclusion record, never in capability requirements or implementation work

## 5. Decision Review

- [x] 5.1 Review the baseline choices for three-state availability, `status=false` occupancy evidence, timeout release, and retained-message freshness; record any approved revision in design and affected specs, then rerun strict validation
- [x] 5.2 Review the choices for location-specific QR entry, Pico plus PIR hardware, the greater-than-ten-second timeout rule, and the `Europe/Vienna` default time zone; record any approved revision and verify affected scenarios remain testable
- [x] 5.3 Review server-side administrative sessions, audit records, production schema migration, and development-only synthetic data; verify the resulting contracts clearly distinguish target behavior from current gaps

## 6. Validation and Publication

- [x] 6.1 Run `openspec validate establish-smartseat-functional-baseline --type change --strict --json` and resolve every reported error or warning; verify the final result is valid
- [x] 6.2 Inspect `git diff -- openspec/changes/establish-smartseat-functional-baseline` and verify the change contains planning artifacts only and no runtime source modifications
- [x] 6.3 Obtain stakeholder approval for the proposal, design decisions, and capability requirements; verify all review changes are captured and tasks 4.1 through 6.2 are complete
- [x] 6.4 Archive the completed documentation-only change with the OpenSpec archive workflow and verify the eight durable specifications exist under `openspec/specs/`

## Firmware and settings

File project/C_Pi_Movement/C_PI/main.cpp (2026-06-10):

#include <format>
#include <string>

#include <ctype.h>
#include <stdio.h>
#include <string.h>

#include "pico/cyw43_arch.h"
#include "pico/stdlib.h"
#include "pico/unique_id.h"

#include "lwip/apps/mqtt.h"
#include "lwip/ip_addr.h"
#include "lwip/netif.h"

#include "WLANConf.h"
#include "hardware/watchdog.h"

// -------------------- App Settings --------------------
#ifndef DEVICE_NAME
#define DEVICE_NAME "1"
#endif

#define MQTT_PORT 1883
#define MQTT_KEEP_ALIVE_S 60

#define MQTT_PUBLISH_QOS 1
#define MQTT_PUBLISH_RETAIN 1

#define TOPIC_STATUS "pico-data"

#define MOTION_SENSOR_PIN 18
#define SEND_INTERVAL_MS 500

// Unique ID string length
#define UNIQUE_ID_STR_LEN (PICO_UNIQUE_BOARD_ID_SIZE_BYTES * 2 + 1)

// -------------------- Logging --------------------
#ifndef INFO_printf
#define INFO_printf printf
#endif

#ifndef ERROR_printf
#define ERROR_printf printf
#endif

// -------------------- State --------------------
typedef struct {
    mqtt_client_t* mqtt_client_inst;
    struct mqtt_connect_client_info_t mqtt_client_info;
    ip_addr_t mqtt_server_address;
    bool connect_done;
} MQTT_CLIENT_DATA_T;

// SYS reset
static void reset_sys() {
    watchdog_enable(1, 1);
    while(1);
}

// -------------------- MQTT helpers --------------------
static void pub_request_cb(__unused void* arg, err_t err) {
    if (err != ERR_OK) {
        ERROR_printf("MQTT publish failed: %d\n", (int)err);
        reset_sys();
    }
}

static void publish_status(MQTT_CLIENT_DATA_T* state, bool motion) {
    cyw43_arch_gpio_put(CYW43_WL_GPIO_LED_PIN, motion);

    std::string payload = "{" +
                          std::format("\"id\":\"{}\",\"status\":{}",
                                      DEVICE_NAME, !motion ? "true" : "false") +
                          "}";

    cyw43_arch_lwip_begin();
    err_t err =
        mqtt_publish(state->mqtt_client_inst, TOPIC_STATUS, payload.data(),
                     (u16_t)payload.length(), MQTT_PUBLISH_QOS,
                     MQTT_PUBLISH_RETAIN, pub_request_cb, state);
    cyw43_arch_lwip_end();

    if (err != ERR_OK) {
        ERROR_printf("mqtt_publish error: %d\n", (int)err);
    }
}

// -------------------- MQTT connect --------------------
static void mqtt_connection_cb(mqtt_client_t* client,
                               void* arg,
                               mqtt_connection_status_t status) {
    (void)client;
    MQTT_CLIENT_DATA_T* state = (MQTT_CLIENT_DATA_T*)arg;

    INFO_printf("MQTT status=%d\n", (int)status);

    if (status == MQTT_CONNECT_ACCEPTED) {
        state->connect_done = true;
        INFO_printf("MQTT connected (client_id=%s)\n",
                    state->mqtt_client_info.client_id);

    }

    else {
        state->connect_done = false;
        ERROR_printf("MQTT connect failed\n");
    }
}

// -------------------- Start MQTT --------------------
static bool start_client(MQTT_CLIENT_DATA_T* state) {
    state->mqtt_client_inst = mqtt_client_new();
    
    if (!state->mqtt_client_inst) {
        ERROR_printf("MQTT client creation failed\n");
        return false;
    }

    INFO_printf("Connecting MQTT to %s:%d\n",
                ipaddr_ntoa(&state->mqtt_server_address), MQTT_PORT);

    state->connect_done = false;

    cyw43_arch_lwip_begin();

    err_t err = mqtt_client_connect(
        state->mqtt_client_inst, &state->mqtt_server_address, MQTT_PORT,
        mqtt_connection_cb, state, &state->mqtt_client_info);

    cyw43_arch_lwip_end();

    if (err == MQTT_CONNECT_DISCONNECTED) {
        INFO_printf("Reconnecting MQTT to %s:%d\n",
                    ipaddr_ntoa(&state->mqtt_server_address), MQTT_PORT);

        cyw43_arch_lwip_begin();

        err = mqtt_client_connect(
            state->mqtt_client_inst, &state->mqtt_server_address, MQTT_PORT,
            mqtt_connection_cb, state, &state->mqtt_client_info);

        cyw43_arch_lwip_end();
    }

    if (err != ERR_OK) {
        ERROR_printf("mqtt_client_connect error: %d\n", (int)err);
        return false;
    }
    return true;
}

// -------------------- Board init --------------------
static int pico_init_board_peripherals(void) {
    stdio_init_all();

    gpio_init(MOTION_SENSOR_PIN);
    gpio_set_dir(MOTION_SENSOR_PIN, GPIO_IN);

    gpio_pull_down(MOTION_SENSOR_PIN);

    if (cyw43_arch_init() != 0) {
        ERROR_printf("cyw43 init failed\n");
        return PICO_ERROR_CONNECT_FAILED;
    }

    return PICO_OK;
}

static void poll_sleep_ms(uint32_t ms) {
    for (uint32_t t = 0; t < ms / 100; t++) {
        cyw43_arch_poll();
        sleep_ms(100);
    }
}

// -------------------- Main --------------------
int main() {
    sleep_ms(1500);

    hard_assert(pico_init_board_peripherals() == PICO_OK);

    static MQTT_CLIENT_DATA_T state;
    memset(&state, 0, sizeof(state));

    char unique_id_buf[UNIQUE_ID_STR_LEN];
    pico_get_unique_board_id_string(unique_id_buf, sizeof(unique_id_buf));
    for (int i = 0; unique_id_buf[i]; i++)
        unique_id_buf[i] = (char)tolower((unsigned char)unique_id_buf[i]);

    static std::string client_id =
        std::format("{} {}", DEVICE_NAME, unique_id_buf);

    state.mqtt_client_info.client_id = client_id.c_str();
    state.mqtt_client_info.keep_alive = MQTT_KEEP_ALIVE_S;

#if defined(MQTT_USERNAMEV) && defined(MQTT_PASSWORDV)
    state.mqtt_client_info.client_user = MQTT_USERNAMEV;
    state.mqtt_client_info.client_pass = MQTT_PASSWORDV;
#endif

    cyw43_arch_enable_sta_mode();
    int w = cyw43_arch_wifi_connect_timeout_ms(WIFI_NAME, WIFI_PASSWORDV,
                                               CYW43_AUTH_WPA2_AES_PSK, 30000);
    if (w != 0) {
        ERROR_printf("WiFi connect failed: %d\n", w);
        cyw43_arch_deinit();
        return 1;
    }

    sleep_ms(500);
    INFO_printf("WiFi IP: %s\n", ipaddr_ntoa(&(netif_list->ip_addr)));

    if (!ipaddr_aton(MQTT_SERVERV, &state.mqtt_server_address)) {
        ERROR_printf("Invalid MQTT_SERVERV: %s\n", MQTT_SERVERV);
        cyw43_arch_deinit();
        return 1;
    }

    if (!start_client(&state)) {
        ERROR_printf("Failed to start MQTT client\n");
        cyw43_arch_deinit();
        return 1;
    }

    while (!state.connect_done) {
        cyw43_arch_poll();
        sleep_ms(100);
    }

    INFO_printf("Publishing motion status every %d ms on topic '%s'\n",
                SEND_INTERVAL_MS, TOPIC_STATUS);

    bool last_motion = false;
    bool first_run = true;

    while (true) {
        cyw43_arch_poll();

        bool motion = gpio_get(MOTION_SENSOR_PIN) ? true : false;

        if (first_run || motion != last_motion) {
            publish_status(&state, motion);
            INFO_printf("Motion changed -> %s (published)\n",
                        !motion ? "true" : "false");

            last_motion = motion;
            first_run = false;
        }

        poll_sleep_ms(SEND_INTERVAL_MS);
    }
}

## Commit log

2025-10-15 added ultraschall sensor analyse
2025-10-15 added rasberry Pi pico 2wh analysis
2025-10-15 fixed raspberryPiPico.txt
2025-10-15 added Tuya Sensor
2025-10-15 added Sensoren to raspberryPiPico.txt
2025-10-15 updatet the raspberry txt
2025-10-20 updated raspberry Pi Pico 2wh file
2025-10-22 added cables to the raspberry Pi file
2025-11-12 Added Inserts to import.sql
2025-11-24 dashboard prototype
2025-12-03 sessionStorage for dashboard current floor
2025-12-03 added inserts
2025-12-17 Added script for the Raspberry PI pico
2025-12-28 Added improved pico 2w script, after having problems with the C-Compiler on windows
    [C_PI.c]
2026-01-27 Added micropython variant to the project, because mse mqtt does not like me. But i got a new problem: the pico can not connect itself to my hotspot
    [C_PI.c]
2026-02-06 trid and failed mqtt
    [C_PI.c]
2026-02-11 Added Motion Sensor Input. Up for testing
2026-02-25 mqtt with working sensor updates
2026-03-18 Added Presentation and fixed c++ Strings
    [main.cpp]
2026-04-13 Added case files
    [Smartseat-Gehäuse.3mf, Smartseat2.f3d]
2026-04-27 Use-Case Diagram added
2026-04-29 added new Case design
    [Smartseat-GehäuseMkiii.3mf, SmartseatGehäuseMkii.3mf]
2026-05-18 changed pico Id and added reconnect to MQTT
2026-06-10 added system reset function
    [main.cpp]
2026-06-17 Added Userguide for the Pico and MQTT, while also adding pictures
2026-09-25 letztes Video hinzugefügt, final touch an der Fehlersuche
